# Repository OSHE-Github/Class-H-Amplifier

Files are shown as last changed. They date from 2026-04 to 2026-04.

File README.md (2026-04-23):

# Class-H-Amplifier

<p align="center">
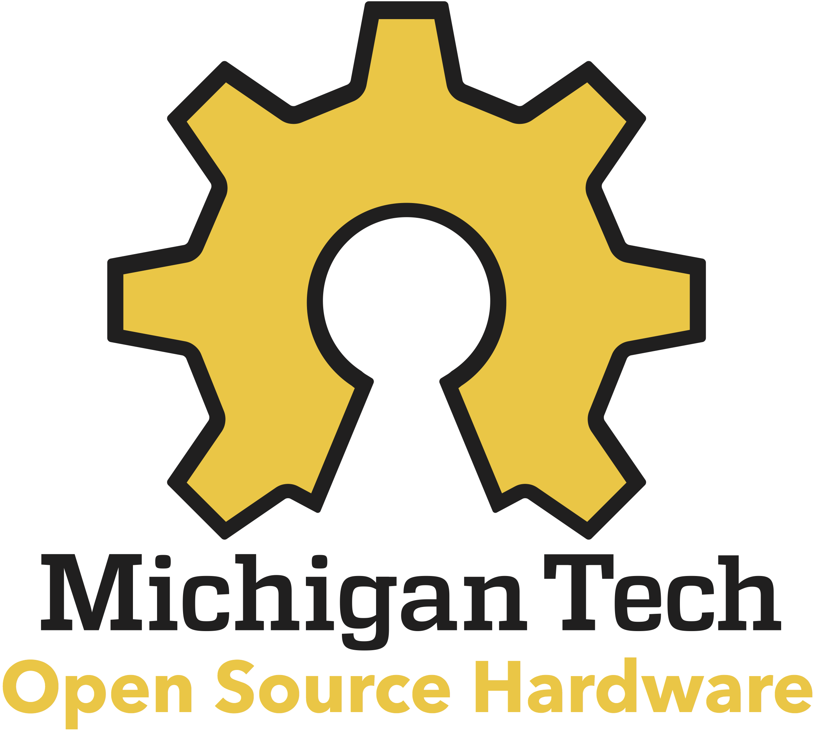
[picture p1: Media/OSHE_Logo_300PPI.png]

</p>

# Project Overview
This project aims to develop a lower-cost Class H amplifier design that can be used not only for audio, but other applications as well with little-to-no modification required. The design is based around a class AB amplifier like many reference designs. This amplifier design includes  documentation on testing and simulations to allow for easy replicability and modification. Key specifications and their impact on performance have been researched and were used to guide the design process. The design has been broken up into sections and most have been successfully simulated. These sections are shown in the block diagram.
<p align="center">

</p>

# Methodology
The class H amplifier was broken down into sections to design separately that would fit together in the end. A class H amplifier differs from other amplifier classes due to its modulating supply rails [1]. A class AB amplifier was frequently used in reference designs and is commonly used especially in audio applications, leading that class to be the choice for this design as well. 

Specifications were defined throughout the process, both to guide the design and to evaluate the actual performance of the completed design. Common amplifier specifications listed on commercial designs include those shown in Table 1, including more which do not apply, are difficult to set a target for,  or are not easily testable. Target values were defined based on typical values and on what was a reasonable goal for this project. The specifications and their values are listed in the table below. 

| Specification | Target |
|---|---|
| Maximum Output Power (Avg) | 100 W |
| Load Impedance | 8 Ω |
| Supply | ±6–45 V |
| Frequency Response | 20 Hz – 20 kHz |
| Total Harmonic Distortion (THD) | < 1% @ 1 kHz |
| Total Harmonic Distortion + Noise (THD+N) | < 1% @ 1 kHz |
| Signal to Noise Ratio (SNR) | ≥ 70 dB |
| Slew Rate | ≥ 5 V/µs |
| Efficiency | > 50% |
| Protection | Overvoltage, undervoltage, reverse polarity, undercurrent |

The full methodology is explained in more detail in the [project report](https://github.com/OSHE-Github/Class-H-Amplifier/blob/main/Documents/Class%20H%20Report.pdf).

# Bill of Materials
### Rail Follower
| Part Description | Part Number | Quantity | Unit Cost | Total Cost |
|---|---|---|---|---|
| 3.3 µH Sepic Inductor | ETQ-P8M3R3JFA | 2 | $2.34 | $4.68 |
| 1 µF Sepic Medium Frequency Cap | CL31B105KCHNFNE | 50 | $0.10 | $5.21 |
| MOSFET N-Channel 100V | SIR870DP-T1-GE3 | 1 | $3.23 | $3.23 |
| 120 V 20A Output Diode | FSV20120V | 1 | $1.30 | $1.30 |
| 10 mΩ 3W Shunt Resistor | CRA2512-FZ-R010ELF | 2 | $0.55 | $1.10 |
| 0.22 µF Soft Start Capacitor | C3216X7R2A224K115AA | 1 | $0.26 | $0.26 |
| 44.2 kΩ Rt Resistor | CRCW040244K2FKEDC | 3 | $0.10 | $0.30 |
| 10 kΩ Resistor | RC0402FR-0710KL | 4 | $0.10 | $0.40 |
| 22 kΩ Comp Resistor | ERA-2AEB223X | 1 | $0.10 | $0.10 |
| 4700 pF Comp Capacitor | GRM155R72A472KA01D | 1 | $0.10 | $0.10 |
| 330 µF Output Filter Capacitor | EKXJ161ELL331MK50S | 4 | $2.98 | $11.92 |
| Test Points | 36-5000-ND | 7 | $0.28 | $1.96 |
| XT-30 | FIT0586 | 2 | $1.90 | $3.80 |
| 7.5 kΩ Resistor | ERA-2AEB752X | 3 | $0.10 | $0.30 |
| 110 kΩ Resistor | 311-110KLRCT-ND | 1 | $0.10 | $0.10 |
| 10 µF ±10% 50V Input Capacitors | CL31A106KBHNNNE | 10 | $0.21 | $2.10 |
| TL072CDT Op-Amp | TL072CDT | 1 | $0.37 | $0.37 |
| 10 kΩ Potentiometer | PDB181-K220K-103B | 1 | $1.40 | $1.40 |
| Signal Rectifier | BAS4002ARPPE6327HTSA1 | 1 | $0.32 | $0.32 |
| 3.5mm Audio Jack | SJ1-3523N | 1 | $0.91 | $0.91 |

### Rail Splitter
| Part Description | Part Number | Quantity | Unit Cost | Total Cost |
|---|---|---|---|---|
| Half-Bridge Gate Driver IC | IRS21531DSTRPBFCT-ND | 2 | $1.24 | $2.48 |
| MOSFET N-CH 100V | SIR870DP-T1-GE3CT-ND | 4 | $3.23 | $12.92 |
| AD820ARZ Op-Amp | 505-AD820ARZ-ND | 2 | $9.11 | $18.22 |
| 10 µH Inductor | PCD2433CT-ND | 5 | $1.13 | $5.65 |
| Zener Diode | 1655-SK56BCT-ND | 5 | $0.49 | $2.45 |
| 5.6 kΩ 0.1% 1/10W | YAG1699CT-ND | 10 | $0.06 | $0.59 |
| 1 nF 1% 25V | 399-C0603C102F3GACTUCT-ND | 10 | $0.50 | $5.04 |
| 10 µF ±20% 100V | 490-GRM32EC72A106ME05KCT-ND | 15 | $0.64 | $9.56 |
| 10 µF ±10% 25V | 399-11939-1-ND | 10 | $0.13 | $1.26 |
| 470 µF 100 V | 493-1379-ND | 10 | $1.09 | $10.92 |
| 47 µF 100 V | 493-1147-ND | 10 | $0.28 | $2.80 |
| 10k Trimmer Pot | TC33X-103ECT-ND | 3 | $0.25 | $0.75 |
| 2200 pF ±20% 25V Ceramic | 399-C0603C222M3RACTUCT-ND | 10 | $0.15 | $1.47 |
| 0.1 µF ±10% 25V Ceramic | 399-C0603C104K3RACTUCT-ND | 10 | $0.01 | $0.10 |
| 33 kΩ ±0.1% 0.1W | P33KDBCT-ND | 10 | $0.06 | $0.61 |
| 330 Ω ±5% 0.1W | 311-330GRCT-ND | 10 | $0.02 | $0.20 |
| 3.9 kΩ ±1% 0.1W | RMCF0603FT3K90CT-ND | 10 | $0.01 | $0.06 |
| 12 kΩ ±0.1% 0.1W | P12KDBCT-ND | 10 | $0.06 | $0.61 |
| 3.3 kΩ ±1% 0.1W | RMCF0603FT3K30CT-ND | 10 | $0.01 | $0.06 |
| 82 kΩ ±5% 0.1W | 311-82KGRCT-ND | 10 | $0.01 | $0.07 |
| 4.7 kΩ ±1% 0.1W | RMCF0603FT4K70CT-ND | 10 | $0.01 | $0.06 |
| 10 Ω ±1% 0.1W | RMCF0603FT10R0CT-ND | 10 | $0.01 | $0.06 |
| 1.5 kΩ ±1% 0.25W | RHM1.50KADCT-ND | 10 | $0.08 | $0.75 |
| Test Point | 36-5005-ND | 30 | $0.26 | $7.68 |

### Class AB Amplifier
| Part Number | Part Description | Quantity | Unit Cost | Total Cost |
|---|---|---|---|---|
| 296-41370-2-ND | OPA454 Op-Amp | 1 | $7.18 | $7.18 |
| MJL21193GOS-ND | Output PNP BJT 250 V 16 A | 1 | $6.26 | $6.26 |
| MJL21194GOS-ND | Output NPN BJT 250 V 16 A | 1 | $6.26 | $6.26 |
| MJE15033GOS-ND | Driver PNP BJT 250 V 8 A | 2 | $2.10 | $4.20 |
| MJE15032GOS-ND | Driver NPN BJT 250 V 8 A | 2 | $2.10 | $4.20 |
| TTC004BQ-ND | NPN 160V 1.5A | 3 | $0.90 | $2.70 |
| TTA004BQ-ND | PNP 160V 1.5A | 2 | $0.81 | $1.62 |
| 541-WSLF3222L4000FE6CT-ND | Output Emitter Resistors 12W | 2 | $3.01 | $6.02 |
| 541-CRCW080540K0FKEACT-ND | 40 kΩ Resistor 1/4W | 2 | $0.12 | $0.24 |
| 541-4187-1-ND | 20 kΩ Resistor 1/4W | 1 | $0.10 | $0.10 |
| 541-1.00KCCT-ND | 1 kΩ Resistor 1/4W | 2 | $0.10 | $0.20 |
| 541-1.10KCCT-ND | 1.1 kΩ Resistor 1/4W | 1 | $0.10 | $0.10 |
| 311-3.60KFRCT-ND | 3.6 kΩ Resistor 1/4W | 1 | $0.10 | $0.10 |
| 541-100CCT-ND | 100 Ω Resistor 1/4W | 3 | $0.10 | $0.30 |
| 709-VPDD202W102K1GV001ECT-ND | 1 nF Filter Capacitor | 1 | $0.17 | $0.17 |
| 399-C1206C104K5RACTUCT-ND | 0.1 µF Bypass Capacitors | 2 | $0.08 | $0.16 |
| 478-12065A300JAT2ACT-ND | 30 pF Capacitor | 1 | $0.28 | $0.28 |
| 1712-CRGH1206F330RCT-ND | 330 Ω Resistor 1/2W | 1 | $0.10 | $0.10 |
| 118-PV36W102C01B00-ND | 1 kΩ Potentiometer | 1 | $1.53 | $1.53 |

## Enclosure
| Part Description | Qty | Link | Cost  |
|---|-----|---|---|
| #2 x 1/4" Pan Head Sheet Metal Screw | 12  | [Link](https://www.amazon.com/dp/B094XVJRQB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)  | $7.49 |
| 3mm x 20mm Hex Bolt | 4 | [Link](https://www.amazon.com/BNUOK-Socket-Screws-Threads-Spanner/dp/B0DJR2Q5LP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)  | $7.49 |
| M3-0.5mm Hex Nut | 4 | [Link](https://www.amazon.com/ZQZ-M3-0-5mm-Stainless-Hardware-Standard/dp/B0CQJK2R5T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)  | $9.99 |

# Tools Used
| Part Description | Part Number | Cost |
|---|---|---|
| Soldering Iron | FX888DX-010BY | $122.99 |
| Oscilliscope | DSOX2004A |  $3306.90 |
| B07BR3F9N6 | 3D Printer |  $169.00 |

Software:
- [LTspice](https://www.analog.com/en/resources/design-tools-and-calculators/ltspice-simulator.html)
- [KiCAD](https://www.kicad.org/download/)
  
# Assembly Overview
1. Gather materials specified in BOM
2. Order materials using provided Gerber files
3. Solder componenents on PCB as specified by schematics
4. Test as described in the [testing procedure](https://github.com/OSHE-Github/Class-H-Amplifier/blob/main/Documents/Testing%20Procedure.md)
5. Dowload enclosure files
6. 3D print enclosure
7. Secure PCBs in enclosure

Detailed assembly guide, including details on LTspice simulations can be found in the [project report](https://github.com/OSHE-Github/Class-H-Amplifier/blob/main/Documents/Class%20H%20Report.pdf)

# Future Recommendations
1. Further testing  for the final rendition of the rail follower board separately and the combination of the rail follower, rail splitter, and AB amplifier
2. Improve distortion, potentially through modification on rail splitter board
3. Further testing is needed for that to understand its maximum load conditions and how those can be improved
4. Additional testing with distortion using more precise equipment or measurement techniques

# References
[1] N. Utomo et al., “An 85.1% Peak Efficiency, Low Power Class H Audio Amplifier With Full Class H Operation,” *IEEE Transactions on Circuits and Systems I: Regular Papers*, vol. 70, no. 12, pp. 1–13, 2023. doi: 10.1109/TCSI.2023.3305622.

[2] S. Munz, “Slew Rate in Audio Amplifiers - What Does it Mean?,” *Audioholics*, Feb. 08, 2013.  
https://www.audioholics.com/audio-amplifier/amplifier-slew-rate

[3] Cambridge Audio, “Amplifier Specifications,” *Cambridge Audio*.  
https://www.cambridgeaudio.com/usa/en/blog/amplifier-specifications

[4] “What is Total Harmonic Distortion (THD)?,” *Audiophile On*, Aug. 16, 2025.  
https://www.audiophileon.com/news/what-is-total-harmonic-distortion-thd

[5] V. Batra, “Modular Concepts: What is an Envelope Follower?,” *Perfect Circuit*, Aug. 22, 2024.  
https://www.perfectcircuit.com/signal/envelope-followers

[6] “What’s the difference between MOSFET and BJT and how to choose?,” *NextPCB*.  
https://www.nextpcb.com/blog/what-is-the-difference-between-mosfet-and-bjt-and-how-to-choose

[7] A. Sedra and K. Smith, *Microelectronic Circuits*. Oxford University Press, 2019.

[8] O. Jørgensen, “What do different amplifier classes mean?,” *Dynaudio*, May 14, 2025.  
https://dynaudio.com/magazine/2025/may/amplifier-classes-ask-the-expert

[9] D. Self, *Audio Power Amplifier Design*, 6th ed. Elsevier / Focal Press, 2013.

[10] Cadence PCB Solutions, “What is Signal to Noise Ratio and How to calculate it?,” 2023.  
https://resources.pcb.cadence.com/blog/2020-what-is-signal-to-noise-ratio-and-how-to-calculate-it

[11] “OSHW,” *Freedom Defined*, 2023.  
https://freedomdefined.org/OSHW

This was also used as a general reference for various amplifier topics and designs that were not directly referenced in this report:

[12] B. Cordell, *Designing Audio Power Amplifiers*. McGraw-Hill Professional, 2010.

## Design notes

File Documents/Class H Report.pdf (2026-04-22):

# Class H Amplifier Report

Prepared by:

Owen Fabbricatore, Tori Frighetto, Peter Kocour, Ben May

### 1. Main Product Image

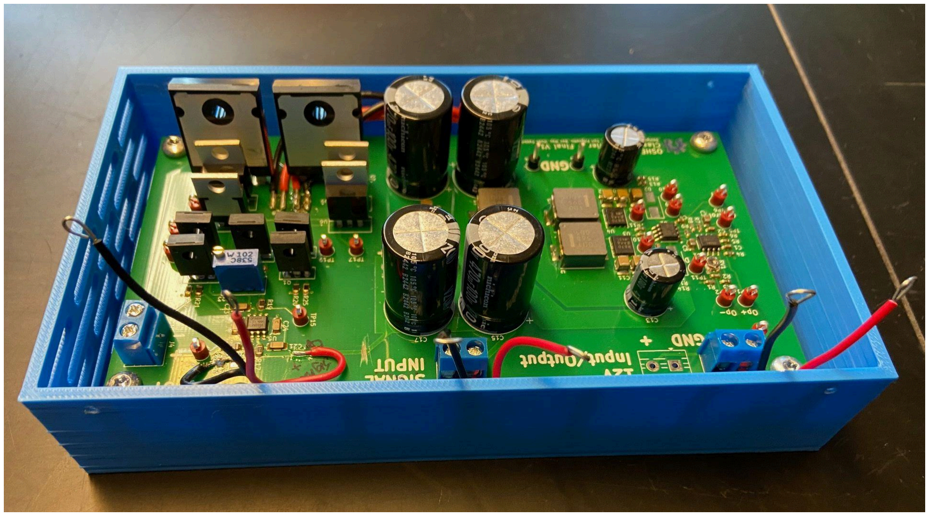
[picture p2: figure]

Figure 1. Product Image

### Table of Contents

### 2. Project Description

This project aims to develop a lower-cost Class H amplifier design that can be used not only for audio, but other applications as well with little-to-no modification required. The design is based around a class AB amplifier like many reference designs. Open source designs are uncommon and not well documented for this class of amplifier and commercial designs are expensive. This amplifier design will include clear documentation to allow for easy replicability and modification. Key specifications and their impact on performance have been researched and were used to guide the design process. The design has been broken up into sections and most have been successfully simulated. These sections are shown in the block diagram.

Figure 2. Block Diagram of Class H Amplifier

### 3. Methodology in Brief

The class H amplifier was broken down into sections to design separately that would fit together in the end. A class H amplifier differs from other amplifier classes due to its modulating supply rails [1]. A class AB amplifier was frequently used in reference designs and is commonly used especially in audio applications, leading that class to be the choice for this design as well.

### 3.1 Specifications

Specifications were defined throughout the process, both to guide the design and to evaluate the actual performance of the completed design. Common amplifier specifications listed on commercial designs include those shown in Table 1, including more which do not apply, are difficult to set a target for, or are not easily testable. Target values were defined based on typical values and on what was a reasonable goal for this project. The specifications and their values are listed in Table 1.

Table 1: Target Specifications

Specification | Target
Maximum Output Power (Avg) | 100 W

Load Impedance | 8Ω
Supply | ±6-45 V
Frequency Response | Minimum: 20 Hz - 20 kHz
Total Harmonic Distortion (THD) | <1% @ 1kHz
Total Harmonic Distortion + Noise (THD+N) | <1% @ 1kHz
Signal to Noise Ratio (SNR) | ≥70 dB
Slew Rate | ≥5 V/µs
Efficiency | >50%
Protection | Overvoltage, undervoltage, reverse polarity, undercurrent

The efficiency was selected based on the typical efficiency of an AB amplifier alone and efficiencies that higher-level class H designs achieved. With AB amplifiers typically having efficiency near 50%, the target is to at least improve on that efficiency. The slew rate was determined by the peak voltage that is expected, set by the defined output power and load, and the frequency which is 20 kHz for this calculation. The calculation for the peak voltage is given by

100 × 8 × | 2 = 40 V | (3.1)

The equation for slew rate is shown below [2].

Slew Rate = 2π × Frequency × Peak Voltage | (3.2)

Total harmonic distortion and total harmonic distortion + noise measures how closely the output of the amplifier matches the original signal and lower percentages are better [3]. In audio applications this affects the sound quality and in other applications this applies to inefficiency. Many high quality amplifiers have THD less than 0.05%, but typically below 1% is considered acceptable for audio products [4]. Acceptable THD varies based on application.

### 3.2 Protection & Enclosure

The Class-H amplifiers safety and protection are maintained through a combination of built in electrical safeguards on the PCB level and passive thermal management into the housing.

### 3.2.1 Integrated Board Protection

Protection is primarily handled via the built in circuitry on the envelope follower, which has overcurrent, undervoltage, overvoltage, and reverse polarity protection. Overcurrent protection is managed by an ATM mini (automotive mini fuse), while the LTC4367 from analog devices that provides the remaining voltage based safeguards. This IC is rated for -40V to 100V and utilizes a three resistor voltage divider to monitor the supply rails.The threshold limits are calculated as follows.

V

OV LIMIT = 0. 5 × 1 +

R

top+ R
mid
R
bot

( )
(3.3)

V

UV LIMIT = 0. 5 × 1 +

R
top
R

bot+R
mid

( )
(3.4)

Solving the above equations will give three resistors, and the SHDN pin from our example can be ignored.

### 3.2.2 General Design

The physical enclosure, designed in Autodesk Inventor, was designed as the final layer of protection by addressing thermal dissipation and electrical safety. Key design considerations include:
1. Thermal Management - To keep the boards cool, it was decided to use a 12V 50mm fan to blow air across the boards. The design features an intake on the top of the enclosure and carefully placed exhaust vents to direct airflow over the boards.
2. Component Layout - The interior is optimized to keep the overall size of the enclosure as small as possible, while still leaving ample space for repair and maintenance. The AB amp is mounted to the bottom plate of the enclosure and the envelope follower is mounted to the top, allowing air to flow over both boards and exhaust out of the front.
3. Exterior Shape - Initial designs were simple and boxy, but it was decided to add texture to the enclosure so the amplifier is more appealing aesthetically.
4. Mechanical Integrity - The enclosure was developed as three pieces, which prioritizes assembly and 3D printing. It was designed so no supports are needed when 3D printing and assembly requires no more than a dozen screws.

### 3.3 Envelope Follower

An envelope follower tracks an input signal’s amplitude and translates it into a voltage which can control other components in a system [5]. In a class H amplifier the envelope follower is necessary in order to control the AB amplifier’s supply voltage based on the input signal. This allows for improved power efficiency. The rail follower is based around the LM5155 in a SEPIC configuration. There are a few key advantages to using a SEPIC converter over other topologies. The first advantage of a SEPIC converter is that it is a buck/boost topology, this allows a wide output voltage range that can swing above or below the input voltage, this enables the rail follower to accept a wide voltage range from 10V-30V while still outputting the required 100 W. Another advantage is because a SEPIC converter input and output are capacitively coupled, no direct path exists from input to output like in a typical boost converter, this provides an extra layer of safety, ensuring no short circuit can occur across the rail follower. The audio envelope is generated by rectifying an AC audio source which is then fed into an op amp and 2uF capacitor and connected to the feedback pin of the LM5155. This setup creates an envelope with a fast rising edge and slow falling edge. Figure 3 shows the schematic for this circuit. The specifications for the circuit are described in Table 2.

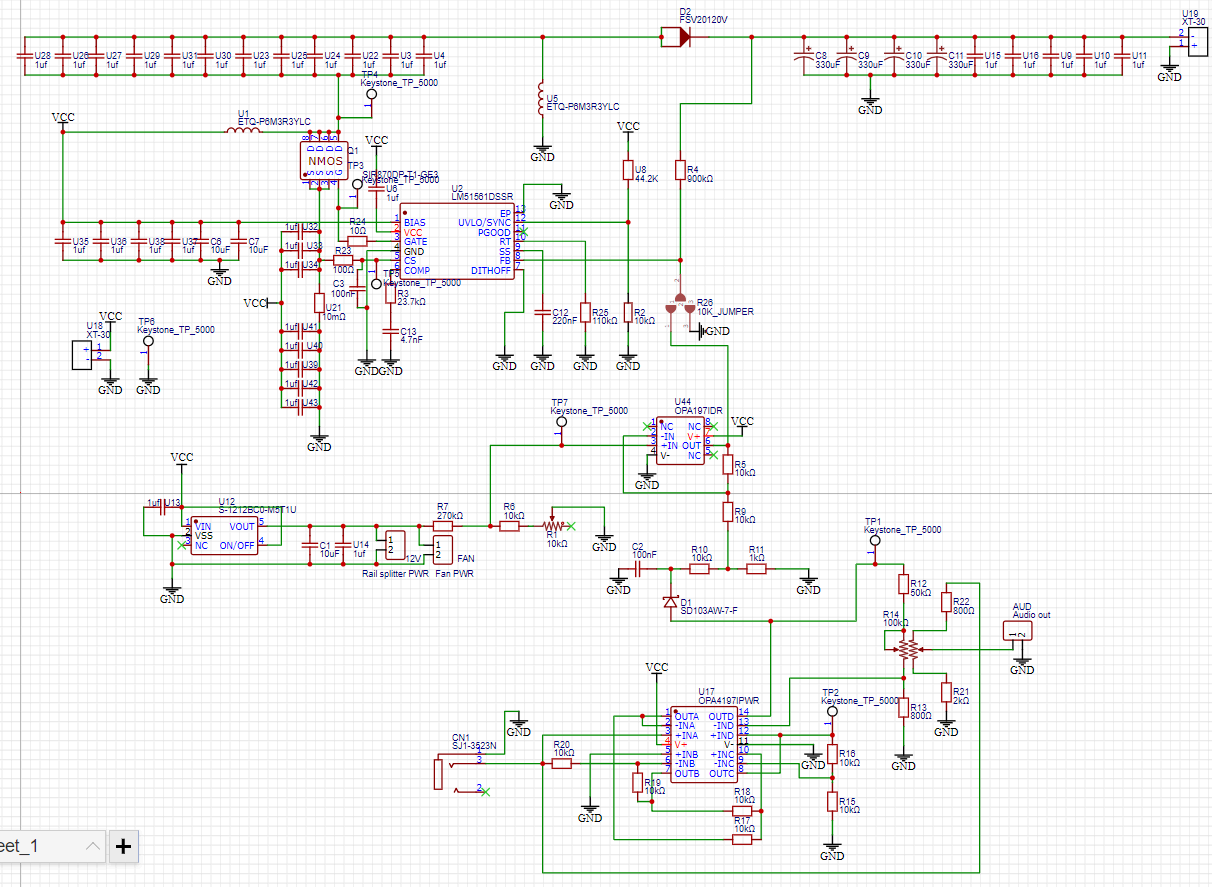
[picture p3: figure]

Figure 3: Envelope Follower Schematic

Table 6:Envelope Follower Circuit Specifications

Input Voltage Range | 10 V-30 V
Output Power | Up to 300 W
Output Voltage Range | 12 V-90 V

Switching Frequency | 250 kHz

### 3.4 Rail Splitter

### 3.4.1 General Design

The rail splitter topology was based off of a design that was made by MrSlehofer on OSHWLAB and is licensed with a CERN Open Hardware License. The initial design utilizes the IR21531D bridge driver, though this device was at the end of life prior to this project. That component was replaced with the IR21531PBF as the half bridge driver for our design. In addition to this, the original operational amplifier used in the feedback loop was replaced with an AD820, this op amp has a higher slew rate which was intended to help increase the response of the feedback loop and ultimately reduce the amount of ripple in the output voltage rails. In addition, the power management portion of the design was removed as our class H amplifier will already have the needed power rails to power the op amp and IC within this portion. The rest of the design stayed relatively the same with the only change being the wattage values of some components to accommodate the higher voltage levels of our desired output.

### 3.4.2 Function Overview

The rail splitter works by having a half bridge driver send alternating PWM signals to two SIR870DP-T1-GE3 MOSFETs. One is between the top and middle rail, while the other is between the middle and bottom rail. As the driver output signals the MOSFET alternates between cutoff and triode, allowing for the rails to evenly split between the voltages. Following this stage there is a filter stage which would level the ripple that is created by the oscillations induced by the opening and closing of the MOSFETs. Finally there is a feedback loop that allows the rails to adapt to different loads that are applied. This feedback loop utilizes an op amp that will switch between its rails based on if the output is past a set threshold. This output is then connected to the RC network that controls the frequency of the output of the half bridge driver.
The default PWM frequency that was selected is based on Equation 3.5 and is based on the values that are selected for RT and CT. For our design we choose RT to be 5.6 kΩ and CT to be 1nF using these values and frequency equation it can be determined that the default frequency is around 125 kHz. When the feedback loop is low it drives the network signal high which opens the gate between high and middle. Contrasting this when the feedback loop is high it drives the network low which then closes that gate and opens the gate to ground. This means that when the output is around the desired voltage the feedback will open and close the gates as needed to maintain that value.

f =

1
1.453 * RT * CT

(3.5)

The output rail of this segment is the original voltage on the top rail, followed by half of that voltage on the middle rail and then ground on the bottom rail. To get a negative and positive rail the middle rail is utilized at the ground reference moving forward. This allows the bottom rail to be a negative rail and the top rail to be the positive rail. To get the desired range of ±6 - 45V the rail splitter is able to handle an input voltage of 12 - 90V.

### 3.5 AB Amplifier

The AB amplifier was initially designed and simulated for the high end, ±45 V, of the decided voltage range in order to select components that were rated for the higher voltage. Modifications to the design are still needed to get the AB amplifier to operate correctly at the lower end of the voltage range.

### 3.5.1 Transistors

Before beginning the design, the use of BJTs or MOSFETs was evaluated to determine which would be most suitable for this design. BJTs offer better linearity than MOSFETs, which is a key factor in this amplifier especially for audio applications. The use of BJTs allows the amplifier to produce a more accurate translation of the output signal. MOSFETs also require careful biasing for gate voltage control which increases the complexity of the design. This is not desirable for the open-source and easily replicable goal of this project. While MOSFETs have better thermal stability and lower power consumption than BJTs, these factors can be managed more easily through thermal considerations in board design [6].

### 3.5.2 General Design

Various general designs were considered for the AB amplifier such as a fully discrete design with BJTs or MOSFETs, a fully differential design with BJTs or MOSFETs, an op-amp input stage with a discrete output stage, or an IC to handle the input and VAS stage with a discrete output stage. The fully discrete designs would provide great flexibility and performance but would come with more components and complexity. A fully differential design would have high efficiency and lower distortion but high complexity because of common-mode feedback and matched stages, making it harder for others to recreate or modify with understanding. Using an IC for the majority of the amplifier would simplify the design significantly making it easier to reproduce as well as decrease the size, but there is less flexibility and limitations in IC availability. An op-amp was chosen for the input stage because it simplifies the design by setting gain and feedback. It can potentially limit performance and there is less control over gain structure, but there is a wide selection of op-amps available with high slew rates and low noise that are also compatible with high voltage rails.

### 3.5.3 Output Stage and Biasing

The class AB output stage, a combination of class A and class B output stages, has two complementary output transistors like a class B output stage but they are biased at small current to reduce crossover distortion. The crossover distortion that would appear in the similar class B stage is reduced because there is a smooth transition between transistor conduction as voltage changes [7]. A class AB output stage is not the most efficient, typically around 50%, but it balances the advantages and disadvantages of the class A and class B designs, specifically linearity and efficiency [8]. Class AB amplifiers are also very common, especially in audio, which gives the advantage of more reference designs to evaluate and learn from. The lower efficiency of the AB output stage over another output stage, like a class D, is not critical because the circuitry added to make it a class H amplifier improves this efficiency.
Biasing methods were considered to supply the base currents for the output stage. Two common methods were evaluated that would both provide thermal stability which was an important consideration due to the power dissipation from the output stage that could damage the output transistors [7]. Diodes are a simple method that would protect the output transistors from damage. A VBE multiplier was used instead of diodes because it provides greater flexibility in the voltage value that sets the quiescent current. Figure 4 shows the VBE multiplier configuration for biasing an AB output stage.

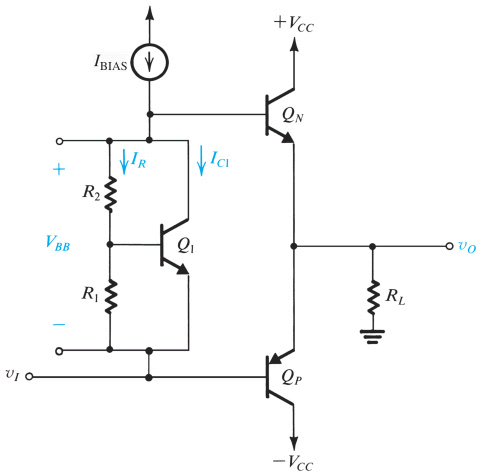
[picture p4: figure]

Figure 4: VBE Multiplier [7]

### 4. Bill of Materials (BOM)

Table 3: Rail Follower

Part Description | Part Number | Quantity | Unit Cost | Total Cost
3.3 µH Sepic Inductor | ETQ-P8M3R3JFA (https://www.digikey.com/en/products/detail/panasonic-electronic-components/ETQ-P8M3R3JFA/7802524) | 2 | $2.34 | $4.68
1 µF Sepic Medium Frequency cap | CL31B105KCHNFNE (https://www.digikey.com/en/products/detail/samsung-electro-mechanics/CL31B105KCHNFNE/3888752) | 50 | $0.10 | $5.21
Mosfet N-Channel 100V | SIR870DP-T1-GE3 (https://www.digikey.com/en/products/detail/vishay-siliconix/SIR870DP-T1-GE3/3748949) | 1 | $3.23 | $3.23
120 V 20A Output Diode | FSV20120V (https://www.digikey.com/en/products/detail/onsemi/FSV20120V/5306666) | 1 | $1.30 | $1.30
10 mOhms 3W Shunt Resistor | CRA2512-FZ-R010ELF (https://www.digikey.com/en/products/detail/bourns-inc/CRA2512-FZ-R010ELF/1775029) | 2 | $0.55 | $1.10

0.22 µF Soft Start Capacitor | C3216X7R2A224K115AA (https://www.digikey.com/en/products/detail/tdk-corporation/C3216X7R2A224K115AA/789677) | 1 | $0.26 | $0.26
44.2 kOhms Rt resistor | CRCW040244K2FKEDC (https://www.digikey.com/en/products/detail/vishay-dale/CRCW040244K2FKEDC/7928528) | 3 | $0.10 | $0.30
10 kOhm Resistor | RC0402FR-0710KL (https://www.digikey.com/en/products/detail/yageo/RC0402FR-0710KL/726523) | 4 | $0.10 | $0.40
22 kOhms Comp Resistor | ERA-2AEB223X (https://www.digikey.com/en/products/detail/panasonic-electronic-components/ERA-2AEB223X/1706037) | 1 | $0.10 | $0.10
4700 pF Comp Capacitor | GRM155R72A472KA01D (https://www.digikey.com/en/products/detail/murata-electronics/GRM155R72A472KA01D/965899) | 1 | $0.10 | $0.10
330 µF Output Filter Capacitor | EKXJ161ELL331MK50S (https://www.digikey.com/en/products/detail/nichicon/UCY2C331MHD6TN/3129796) | 4 | $2.98 | $11.92
Test Points | 36-5000-ND (https://www.digikey.com/en/products/detail/keystone-electronics/5000/255326?gclsrc=aw.ds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) | 7 | $0.28 | $1.96
XT-30 | FIT0586 (https://www.digikey.com/en/products/detail/dfrobot/FIT0586/9559255?gclsrc=aw.ds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) | 2 | $1.90 | $3.80
7.5 kOhm Resistor | ERA-2AEB752X (https://www.digikey.com/en/products/detail/panasonic-electronic-components/ERA-2AEB752X/1706026) | 3 | $0.10 | $0.30
110 kOhm Resistor | 311-110KLRCT-ND (https://www.digikey.com/en/products/detail/yageo/RC0402FR-07110KL/726531) | 1 | $0.10 | $0.10
10 µF ±10% 50V Input Capacitors | CL31A106KBHNNNE (https://www.digikey.com/en/products/detail/samsung-electro-mechanics/CL31A106KBHNNNE/3888534) | 10 | $0.21 | $2.10
TL072CDT Op-Amp | TL072CDT (https://www.digikey.com/en/products/detail/stmicroelectronics/TL072CDT/599372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) | 1 | $0.37 | $0.37
10 kOhm Potentiometer | PDB181-K220K-103B (https://www.digikey.com/en/products/detail/bourns-inc/PDB181-K220K-103B/3780701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) | 1 | $1.40 | $1.40
Signal Rectifier | BAS4002ARPPE6327HTSA1 (https://www.digikey.com/en/products/detail/infineon-technologies/BAS4002ARPPE6327HTSA1/2023140) | 1 | $0.32 | $0.32
3.5mm Audio Jack | SJ1-3523N (https://www.digikey.com/en/products/detail/same-sky-formerly-cui-devices/SJ1-3523N/738689) | 1 | $0.91 | $0.91

Table 4: Rail Splitter

Part Description | Part Number | Quantity | Unit Cost | Total Cost
Half-Bridge Gate Driver IC | IRS21531DSTRPBFCT-ND (https://www.digikey.com/en/products/detail/infineon-technologies/irs21531dstrpbf/1300645) | 2 | $1.24 | $2.48
MOSFET N-CH 100V | SIR870DP-T1-GE3CT-ND (https://www.digikey.com/en/products/detail/vishay-siliconix/SIR870DP-T1-GE3/3748949) | 4 | $3.23 | $12.92
AD820ARZ Op-Amp | 505-AD820ARZ-ND (https://www.digikey.com/en/products/detail/analog-devices-inc/AD820ARZ/620917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) | 2 | $9.11 | $18.22
10uH Inductor | PCD2433CT-ND (https://www.digikey.com/en/products/detail/panasonic-electronic-components/ETQ-P5M100YFC/5357809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) | 5 | $1.13 | $5.65
Zener Diode | 1655-SK56BCT-ND (https://www.digikey.com/en/products/detail/smc-diode-solutions/SK56B/6022696) | 5 | $0.49 | $2.45
5.6K 0.1% 1/10W | YAG1699CT-ND (https://www.digikey.com/en/products/detail/yageo/RT0603BRD075K6L/1072597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) | 10 | $0.06 | $0.59
1nF 1% 25V | 399-C0603C102F3GACTUC | 10 | $0.50 | $5.04
T-ND (https://www.digikey.com/en/products/detail/kemet/C0603C102F3GACTU/2199692)
10 µF ±20% 100V | 490-GRM32EC72A106ME0 5KCT-ND (https://www.digikey.com/en/products/detail/murata-electronics/GRM32EC72A106ME05K/17860690) | 15 | $0.64 | $9.56
10 µF ±10% 25V | 399-11939-1-ND (https://www.digikey.com/en/products/detail/kemet/C0805C106K3PACTU/5267604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) | 10 | $0.13 | $1.26
470 µF 100 V | 493-1379-ND (https://www.digikey.com/en/products/detail/nichicon/UVZ2A471MHD/589120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) | 10 | $1.09 | $10.92
47 µF 100 V | 493-1147-ND (https://www.digikey.com/en/products/detail/nichicon/UVR2A470MPD/588888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) | 10 | $0.28 | $2.80
10k Trimmer Pot | TC33X-103ECT-ND (https://www.digikey.com/en/products/detail/bourns-inc/TC33X-2-103E/612858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) | 3 | $0.25 | $0.75
2200 pF ±20% 25V Ceramic | 399-C0603C222M3RACTU (https://www.digikey.com/en/products/detail/kemet/C0603C222M3RACTU/2200267) | 10 | $0.15 | $1.47

| CT-ND (https://www.digikey.com/en/products/detail/kemet/C0603C222M3RACTU/2200267)
0.1 µF ±10% 25V Ceramic | 399-C0603C104K3RACTUC T-ND (https://www.digikey.com/en/products/detail/kemet/C0603C104K3RACTU/416044) | 10 | $0.01 | $0.10
33 kOhms ±0.1% 0.1W | P33KDBCT-ND (https://www.digikey.com/en/products/detail/panasonic-electronic-components/ERA-3AEB333V/1465890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) | 10 | $0.06 | $0.61
330 Ohms ±5% 0.1W | 311-330GRCT-ND (https://www.digikey.com/en/products/detail/yageo/RC0603JR-07330RL/726769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) | 10 | $0.02 | $0.20
3.9 kOhms ±1% 0.1W | RMCF0603FT3K90CT-ND (https://www.digikey.com/en/products/detail/stackpole-electronics-inc/RMCF0603FT3K90/1713908) | 10 | $0.01 | $0.06
12 kOhms ±0.1% 0.1W | P12KDBCT-ND (http://www.digikey.com/en/products/detail/panasonic-electronic-components/ERA-3AEB123V/1465880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) | 10 | $0.06 | $0.61
3.3 kOhms ±1% 0.1W | RMCF0603FT3K30CT-ND (https://www.digikey.com/en/products/detail/stackpole-electronics-inc/RMCF0603FT3K30/1761032) | 10 | $0.01 | $0.06
82 kOhms ±5% 0.1W | 311-82KGRCT-ND (https://www.digikey.com/en/products/detail/yageo/RC0603JR-0782KL/726835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) | 10 | $0.01 | $0.07
4.7 kOhms ±1% 0.1W | RMCF0603FT4K70CT-ND (https://www.digikey.com/en/products/detail/stackpole-electronics-inc/RMCF0603FT4K70/1760998) | 10 | $0.01 | $0.06
10 Ohms ±1% 0.1W | RMCF0603FT10R0CT-ND (https://www.digikey.com/en/products/detail/stackpole-electronics-inc/RMCF0603FT10R0/1761152) | 10 | $0.01 | $0.06
1.5 kOhms ±1% 0.25W | RHM1.50KADCT-ND (https://www.digikey.com/en/products/detail/rohm-semiconductor/ESR03EZPF1501/1983433) | 10 | $0.08 | $0.75
Test Point | 36-5005-ND (https://www.digikey.com/en/products/detail/keystone-electronics/5005/255329) | 30 | $0.26 | $7.68

Table 5: AB Amplifier

Part Number | Part Description | Quantity | Unit Cost | Total Cost
OPA454 Op-amp | 296-41370-2-ND (https://www.digikey.com/en/products/detail/texas-instruments/OPA454AIDDAR/1899758) | 1 | $7.18 | $7.18
Output PNP BJT 250 V 16 A | MJL21193GOS-ND (https://www.digikey.com/en/products/detail/onsemi/MJL21193G/919549) | 1 | $6.26 | $6.26
Output NPN BJT 250 V 16 A | MJL21194GOS-ND (https://www.digikey.com/en/products/detail/onsemi/MJL21194G/919550) | 1 | $6.26 | $6.26
Driver PNP BJT 250 V 8 A | MJE15033GOS-ND (https://www.digikey.com/en/products/detail/onsemi/mje15033g/919494) | 2 | $2.10 | $4.20
Driver NPN BJT 250 V 8 A | MJE15032GOS-ND (https://www.digikey.com/en/products/detail/onsemi/MJE15032G/919493?s=N4IgTCBcDaILYCsCmBGArABgMxgOYgF0BfIA) | 2 | $2.10 | $4.20
NPN 160V 1.5A | TTC004BQ-ND (https://www.digikey.com/en/products/detail/toshiba-semiconductor-and-storage/TTC004B-Q/6600430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) | 3 | $0.90 | $2.70
PNP 160V 1.5A | TTA004BQ-ND (https://www.digikey.com/en/products/detail/toshiba-semiconductor-and-storage/TTA004B-Q/6600426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) | 2 | $0.81 | $1.62
Output Emitter Resistors 12W | 541-WSLF3222L4000FE6CT-N D (https://www.digikey.com/en/products/detail/vishay-dale/WSLF3222L4000FE6/25701010) | 2 | $3.01 | $6.02
40 kOhm Resistor 1/4W | 541-CRCW080540K0FKEACT-N D (https://www.digikey.com/en/products/detail/vishay-dale/CRCW080540K0FKEA/5075239) | 2 | $0.12 | $0.24
20 kOhm Resistor 1/4W | 541-4187-1-ND (https://www.digikey.com/en/products/detail/vishay-dale/CRCW120620K0FKEAC/7928609) | 1 | $0.10 | $0.10
1 kOhm Resistor 1/4W | 541-1.00KCCT-ND (https://www.digikey.com/en/products/detail/vishay-dale/CRCW08051K00FKEA/1175637) | 2 | $0.10 | $0.20
1.1 kOhm Resistor 1/4W | 541-1.10KCCT-ND (https://www.digikey.com/en/products/detail/vishay-dale/CRCW08051K10FKEA/1175641) | 1 | $0.10 | $0.10
3.6 kOhm Resistor 1/4W | 311-3.60KFRCT-ND (https://www.digikey.com/en/products/detail/yageo/RC1206FR-073K6L/728781) | 1 | $0.10 | $0.10
100 Ohm resistor 1/4W | 541-100CCT-ND (https://www.digikey.com/en/products/detail/vishay-dale/CRCW0805100RFKEA/1175523) | 3 | $0.10 | $0.30
1 nF Filter Capacitor | 709-VPDD202W102K1GV001E CT-ND (https://www.digikey.com/en/products/detail/johanson-dielectrics-inc/VPDD202W102K1GV001E/1556359) | 1 | $0.17 | $0.17

0.1 µF Bypass Capacitors | 399-C1206C104K5RACTUCT-N D (https://www.digikey.com/en/products/detail/kemet/C1206C104K5RACTU/411248) | 2 | $0.08 | $0.16
30 pF Capacitor | 478-12065A300JAT2ACT-ND (https://www.digikey.com/en/products/detail/kyocera-avx/12065A300JAT2A/1604535) | 1 | $0.28 | $0.28
330 Ohm Resistor 1/2W | 1712-CRGH1206F330RCT-ND (https://www.digikey.com/en/products/detail/te-connectivity-passive-product/CRGH1206F330R/7495002) | 1 | $0.10 | $0.10
1 kOhm Potentiometer | 118-PV36W102C01B00-ND (https://www.digikey.ca/en/products/detail/bourns-inc/PV36W102C01B00/666501) | 1 | $1.53 | $1.53

Table 6: Enclosure

Part | Qty | Link | Cost
#2 x 1/4" Pan Head Sheet Metal Screw | 12 | Link (https://www.amazon.com/dp/B094XVJRQB?oas=true) | $7.49

3mm x 20mm Hex Bolt | 4 | Link (https://www.amazon.com/BNUOK-Socket-Screws-Threads-Spanner/dp/B0DJR2Q5LP?s=industrial) | $7.49
M3-0.5mm Hex Nut | 4 | Link (https://www.amazon.com/ZQZ-M3-0-5mm-Stainless-Hardware-Standard/dp/B0CQJK2R5T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) | $9.99

### 5. Tools Used

Table 7: Tools Used

Part Number | Part Description | Quantity | Unit Cost | Total Cost
FX888DX-010BY (https://www.jensentools.com/product/10305267-FX888DX-010BY) | Soldering Iron | 1 | $122.99 | $122.99
DOS1102 (https://www.amazon.com/HANMATEK-Bandwidth-Oscilloscope-Channels-Professional/dp/B0833YFNKP) | Oscilloscope | 1 | $135.99 | $135.99
B07BR3F9N6 (https://www.amazon.com/Comgrow-Creality-Ender-Aluminum-220x220x250mm/dp/B07BR3F9N6) | 3D Printer | 1 | $169.00 | $169.00

Software Used:
- LTspice:
https://www.analog.com/en/resources/design-tools-and-calculators/ltspice-simulator.html
- KiCAD: https://www.kicad.org/download/

### 6. Assembly Instructions

### 6.1 Downloading and Setting Up LTspice

1. Go to
https://www.analog.com/en/resources/design-tools-and-calculators/ltspice-simulator.html
2. Choose the correct download for your operating system (Windows or Mac)
3. Download the schematic, symbol, and model files from github at https://github.com/OSHE-Github/Class-H-Amplifier

4. Put the downloaded files in your LTspice folder in Documents/LTspice
5. To open the schematic files, double click on them in the folder or open within LTspice by choosing File -> Open and then select an LTspice Schematic File

### 6.2 Protection Simulation Setup

1. Open the LTC4367_12_20.asc file in LTspice
2. Use the following for the voltage source
a. PWL(0 0 10m 15 50m 15 51m 22 100m 22 101m 15 150m 15 151m 10 200m 10 201m 15 250m 15 251m -15 300m -15)
3. Right click on the .dc directive to run a voltage sweep simulation
4. Run the simulation
5. Click on Vout and Vin to view the waveforms on the plot

### 6.3 Rail Splitter Simulation Setup

1. Open the Rail_Splitter_Sim.asc file in LTspice
2. Right click on the voltage source V2 circled in red in Figure 5

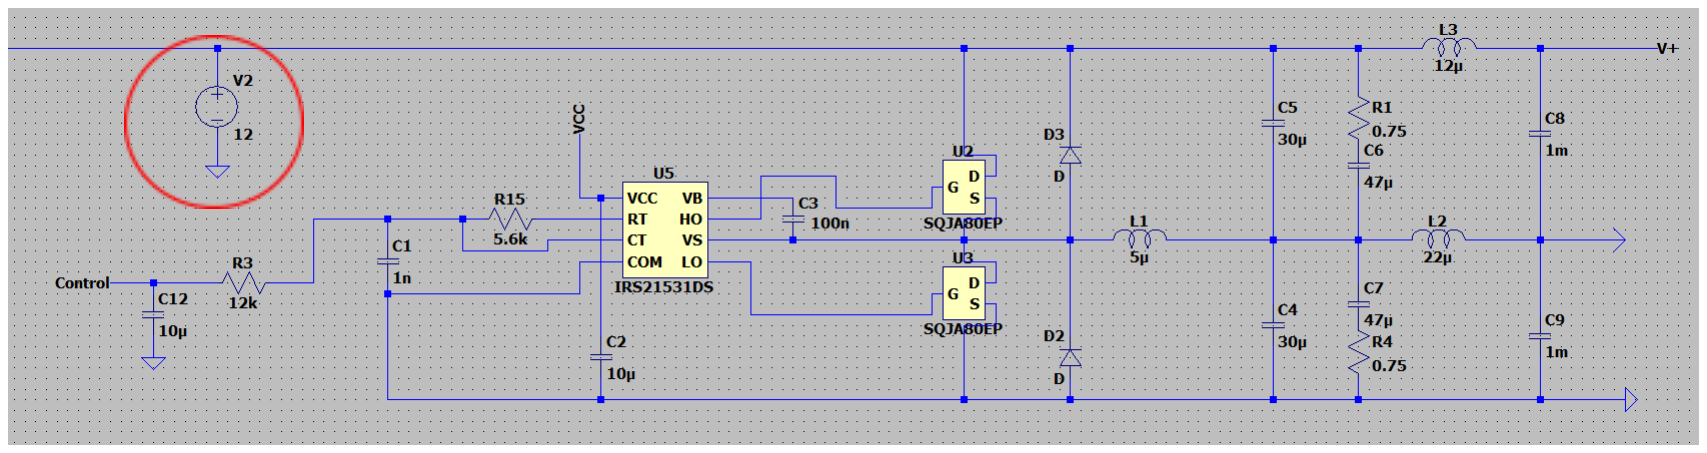
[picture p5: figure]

Figure 5: Rail Splitter
3. In the voltage source settings window set the voltage to twice the values you want your rails to be

Figure 6: Voltage Source Settings
4. Select the run button in the top right corner, or press alt+r on the keyboard
5. Probe the value of V+ and COM (the middle rail)
a. Confirm that the rails properly split your desired voltage
6. Probe around the circuit to measure any other desired values

### 6.4 AB Amplifier Simulation Setup

6.4.1 1 kHz Transient Simulation

1. Open the ABAmp_models85.asc file in LTspice
2. Right click on the voltage source V3 and choose SINE under functions.
3. Below the functions, enter the following parameters
a. Amplitude[V]: 1
b. Freq[Hz]: 1k
c. Ncycles: 16 - this can be changed
d. The other parameters can be left at 0

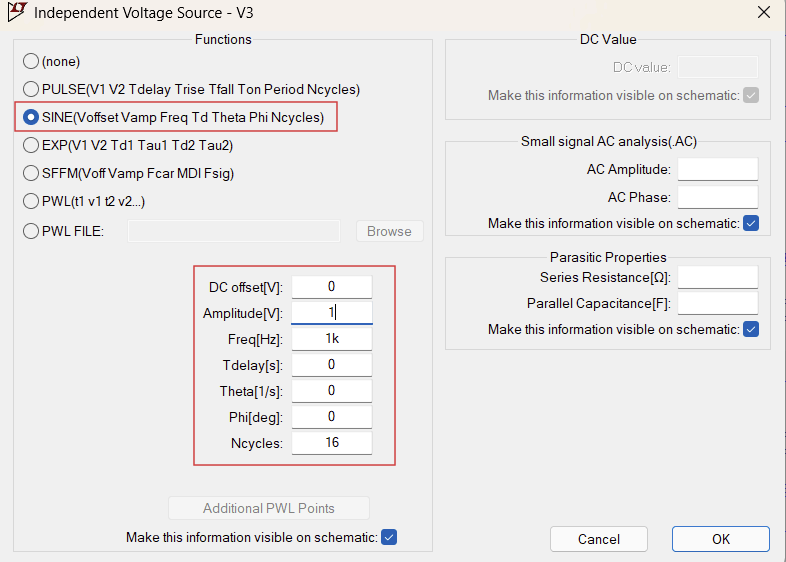
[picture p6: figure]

Figure 7: Voltage Source Configuration Window
4. Right click on the text “.tran 0 16ms 0 0.488u”
a. This is the syntax to run the transient simulation. The amount of time (16ms) for the simulation to run can be changed, but should run for at least a few milliseconds for it to stabilize.
b. The maximum timestep (0.488u) can also be changed and may give slightly different results but will mostly be the same. Too high of a max timestep may prevent the simulation from converging.

Figure 8: Transient Simulation Directive
5. Click OK
6. Press the Run button on the toolbar
7. The details of the simulation running will be shown at the bottom of the screen
8. A window will pop up that may show waveforms already selected or it may be blank
a. If blank, click on the Vout signal on the schematic and the waveform will appear in the other window. Alt + click on the resistor RL will bring up the waveform showing the output power
9. CTRL + click on the trace names will bring up a small window showing the RMS value of the signal and the average value
a. Here the RMS output voltage and the average power can be seen
10. The input voltage V3 can be adjusted by increasing the amplitude
a. 1.5 V amplitude gives the maximum average output power. Increasing beyond that the simulation will fail to converge. This issue is being worked on

### 6.4.2 Total Harmonic Distortion Simulation

1. This simulation uses the same input voltage settings and the same .tran analysis. The directive .four 1kHz 10 4 V(vout) is already included to view the FFT and THD
2. With a 1V amplitude, rerun the transient simulation

3. Right click anywhere on the plot and choose View -> FFT

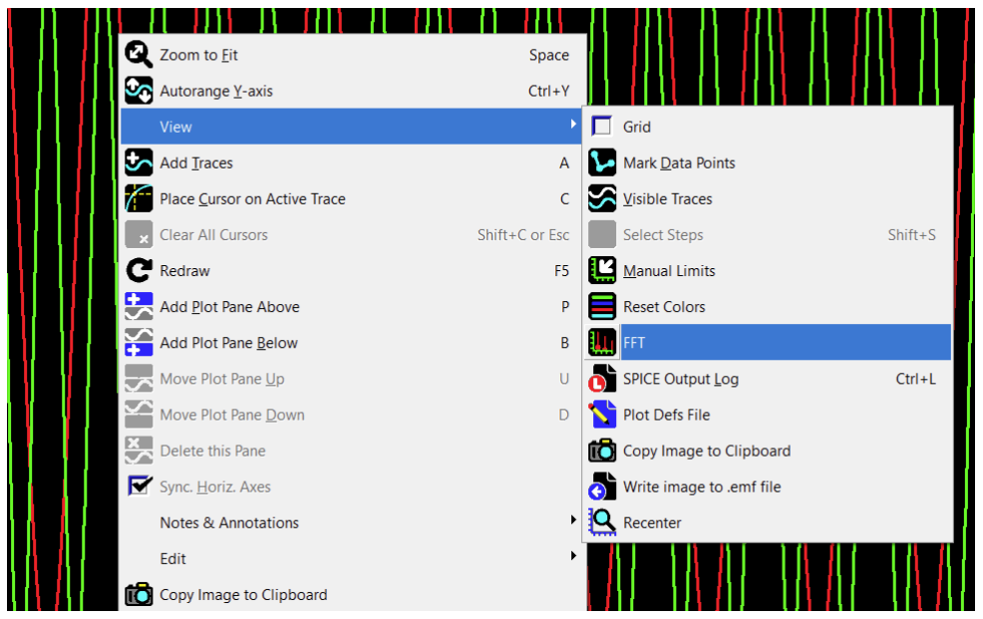
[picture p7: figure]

Figure 9: View FFT Option

4. A window will pop up with settings, shown below

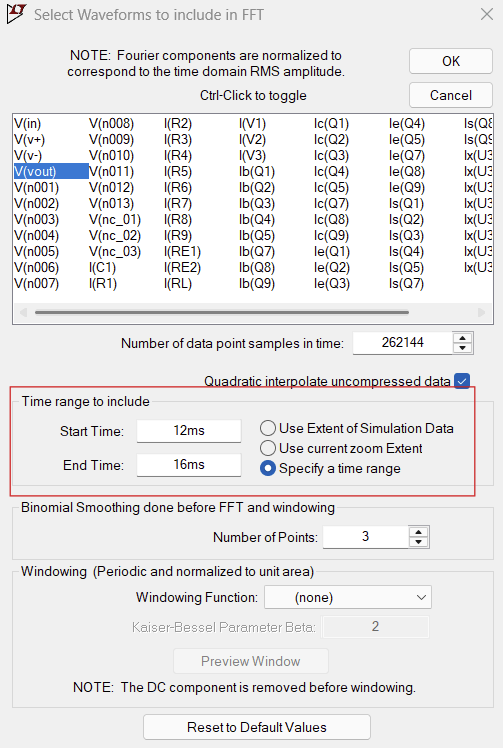
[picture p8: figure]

Figure 10: FFT Settings
5. Under time range select “Specify a time range” and use the simulation time for the end time and use the end time - 4ms for the start time

6. Click OK and the FFT plot will appear. The resolution will change depending on the timestep used in the simulation
7. Hit CTRL + L and the Spice Output Log will pop up
8. Scroll to the bottom to see the Fourier components details and the partial and total harmonic distortion

### 6.4.3 Noise Simulation

1. In the schematic window right click on the directive .noise V(vout) V3 dec 20 20 20k
2. A window with options to configure the analysis will appear. The current configuration is shown below

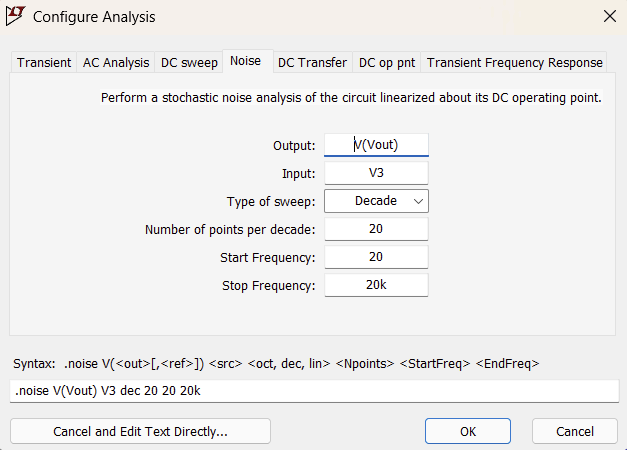
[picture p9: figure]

Figure 11: Noise Simulation Configuration

3. Change the settings if necessary and hit OK
4. Run the simulation
5. A blank plot will open, click on Vout on the schematic to plot that signal
6. CTRL + left click on the trace name v(onoise) will bring up a window with the total RMS noise

Figure 12: Noise Details Window

### 6.4.4 Frequency Response Simulation

1. Change the input voltage V3 to an AC 1 source by using the configuration shown below

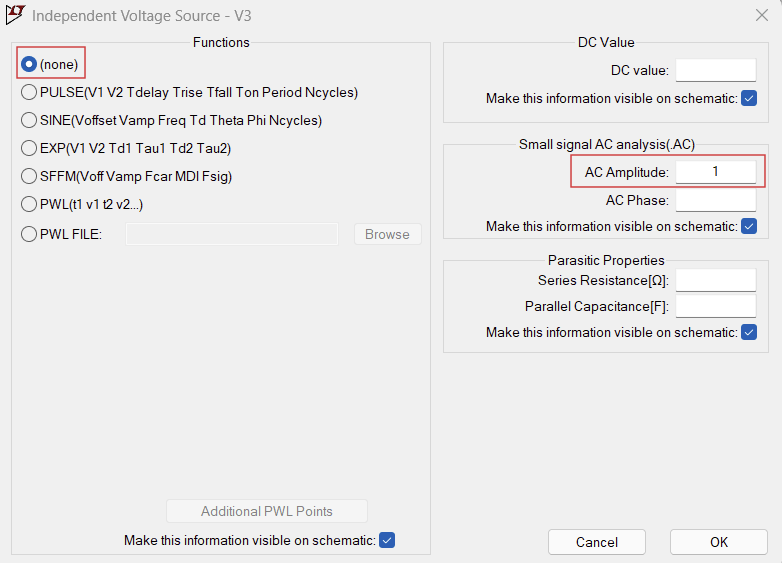
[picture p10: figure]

Figure 13: Voltage Configuration for Frequency Response Simulation
2. Right click on the directive .ac dec 10 20 1Meg
3. A window to configure the analysis will appear
a. The current configuration is a decade sweep with 10 points per decade from 20 Hz to 1 MHz
4. Hit OK and run the simulation
5. A blank plot window will appear
6. Click on Vout on the schematic window and the plot will appear with the frequency response
7. Left click on the trace name and a cursor will appear. Leave this cursor on the flat slope
8. Left click again on the trace and a second cursor will appear
9. Drag this cursor to the right until there is a difference of about 3dB between the two cursor magnitudes

Figure 14: Frequency Response Plot Cursor Details
10. The frequency response will be the frequency at cursor 1 to the frequency at cursor 2

### 6.5 Hardware Setup

### 6.5.1 Rail Follower Assembly

Following the schematic for the Rail follower and the bill of materials in section 4, place each component in its corresponding location on the PCB. The KiCAD file for the PCB can be found here: https://github.com/OSHE-Github/Class-H-Amplifier/tree/main/ClassH_PCB/envelope_follower

### 6.5.2 Rail Splitter and AB Amplifier Assembly

Following the schematics for the rail splitter in Figure 15 and the AB amplifier in Figure 16, along with the Bill of Materials and the reference designators, place each component onto the corresponding location on the PCB in Figure 17. All KiCAD files can be found on our GitHub under “ClassH_PCB_FINAL” at https://github.com/OSHE-Github/Class-H-Amplifier/tree/main/ClassH_PCB

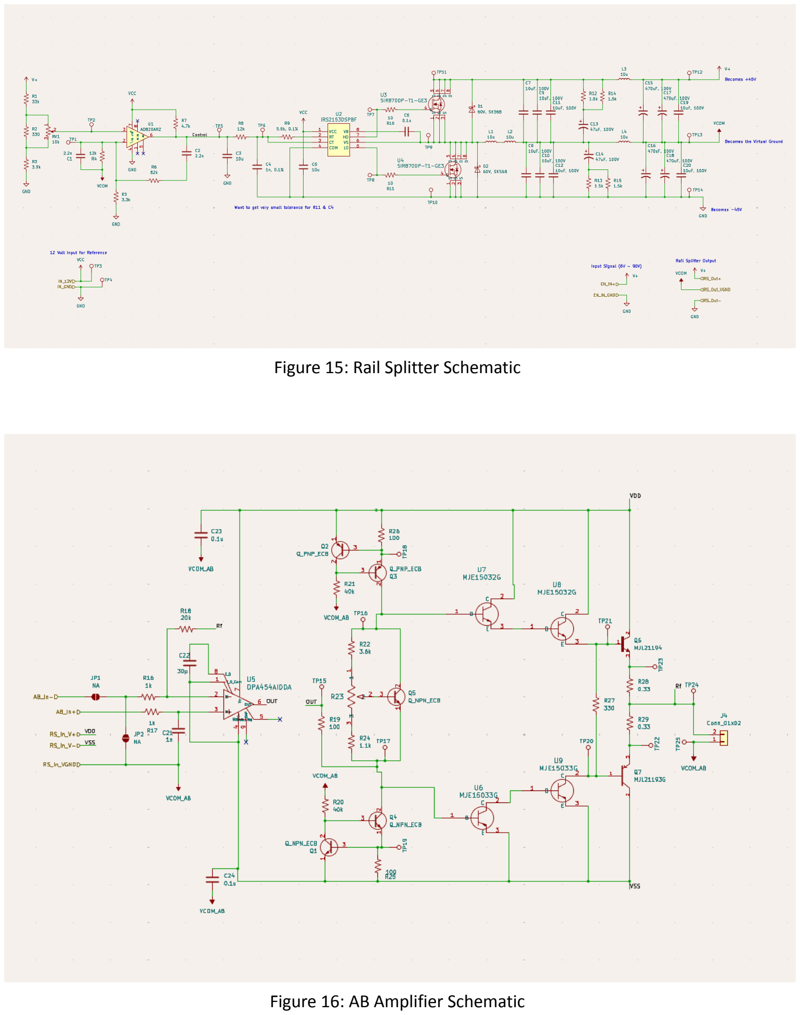
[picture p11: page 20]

Figure 15: Rail Splitter Schematic

Figure 16: AB Amplifier Schematic

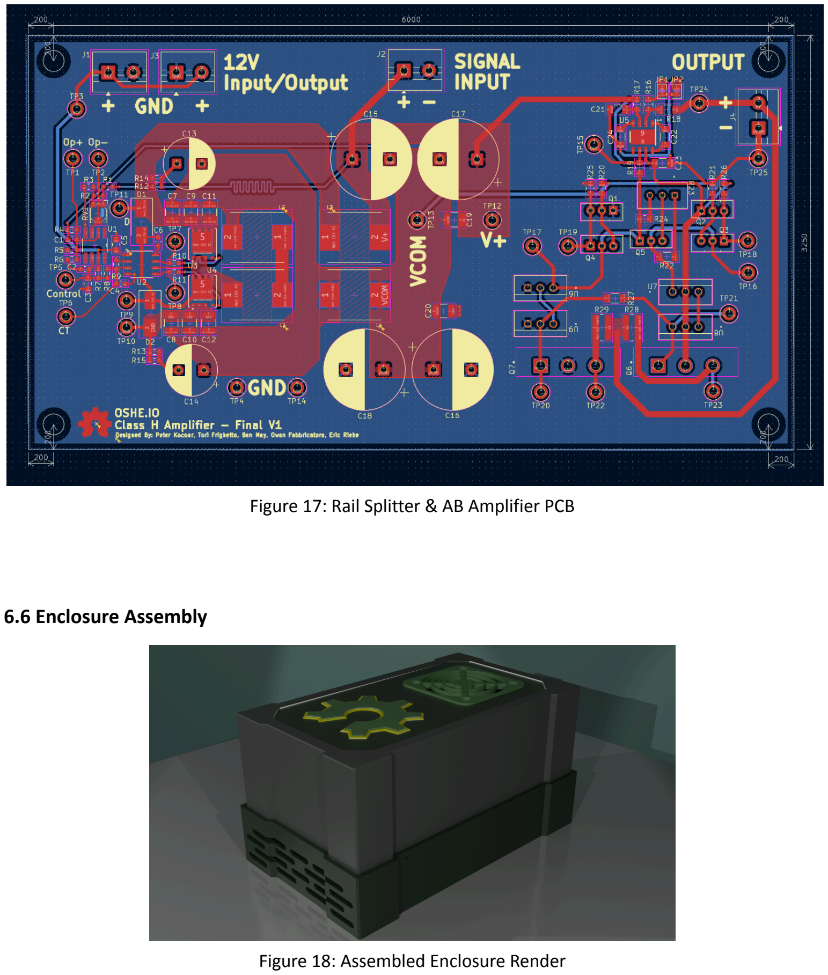
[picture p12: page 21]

Figure 17: Rail Splitter & AB Amplifier PCB

### 6.6 Enclosure Assembly

Figure 18: Assembled Enclosure Render

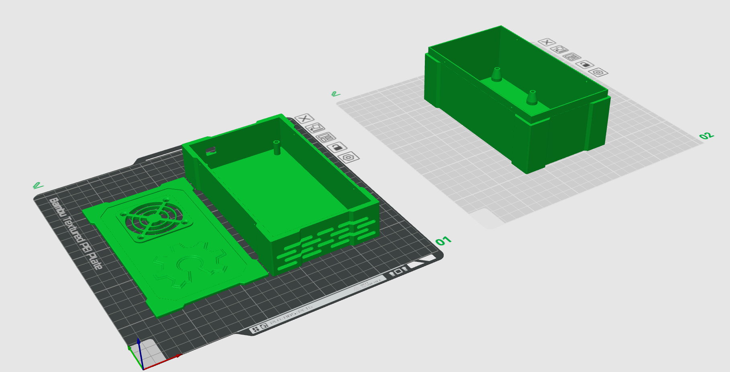
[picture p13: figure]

Figure 19: Printing Plate Layout The enclosure for the Class-H amplifier consists of three distinct parts: The bottom piece, (second from left, figure above) the middle piece (printed upside down, right in figure above), and the top piece (left, figure above.)

The bottom and middle pieces are carefully designed to fit perfectly together, with a tolerance of 0.1mm. If your printer cannot handle this tolerance, it is recommended to scale the middle piece on all axes slightly to ensure a good fit.

### 6.6.1 Enclosure 3D Printing

It is recommended to use the default print settings for all pieces. However, in testing it was found that 5% infill of any shape worked best, and ironing specifically for the top piece helped enhance the quality of the print. The layout shown above is the best, and rotating any of the pieces is not recommended. The size of the build plate in the image is 256mm³

, but it may be printed on as small as 180mm³ ,with each
piece being on its own plate.

### 6.6.2 Enclosure Assembly

To assemble the enclosure you will need the times listed in Table 6.

The #2 x 1/4" Pan Head Sheet Metal Screws are used to connect the rail splitter + AB amplifier board and envelope follower board and to the enclosure on the bottom and top, respectively. They are also used on either side of the enclosure to secure the bottom piece to the middle piece.

The 3mm x 20mm Hex Bolts are used to secure the 50mm x 50mm fan attached to the top of the enclosure. They do not thread in similar to the other screws, and they require nuts attached to the underside of the top piece to secure the fan.

The figure on the left below shows the four mounting holes for the 50mm x 50mm fan and the right image shows the holes for the screws to secure the middle and bottom piece.

### 7. Characterization Data

### 7.1 Protection Simulations

For the protection of the amplifier the LTC4367 IC was used. This allowed for the protection parameters to be set as seen in Table 8. These values were then tested using the LTspice simulation with the out being seen in Figure 15. This figure shows the inputted voltage in green and the voltage supplies to the amplifier in blue. It can be seen that when in reverse bias the voltage is blocked. Also when the voltage is below 12V or above 20V the output voltage is set to 0V. This was the intended result of the protection stage to allow for safe use.

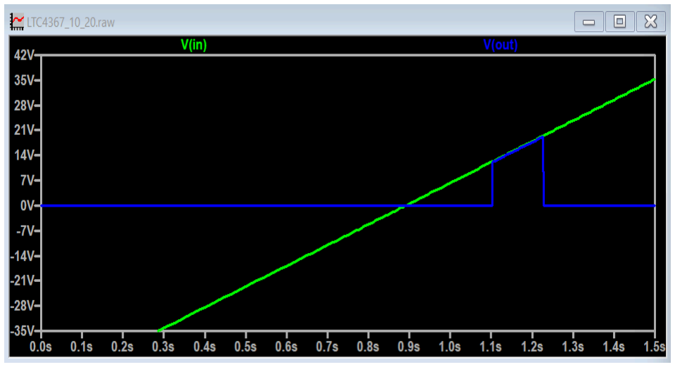
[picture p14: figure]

Figure 20: LTC4367 DC Sweep Simulation

Table 8: Protection Parameters

Protection Type | Protection Parameters
Over Voltage Protection | 20V - 100V

Under Voltage Protection | 0V - 12V
Reverse Polarity | -40V - 0V
Over Current | ATM Mini Fuse

### 7.2 Rail Splitter Simulations

The rail splitter was simulated at various V+ values within the rail splitter’s input voltage range of 12-90
V. At the low end of the range with V+ = 12V, shown in Figure 21, the Vcom value is approximately half the V+ value and that value is shown in Figure 22.

Figure 21. 12V V+

Figure 22. Vcom Value at V+ = 12V

At this input voltage, V+ experiences ripple, which is measured with the recorded value in Figure
23. Figure 24 shows the two waveforms.

Figure 23: V+ Voltage Ripple

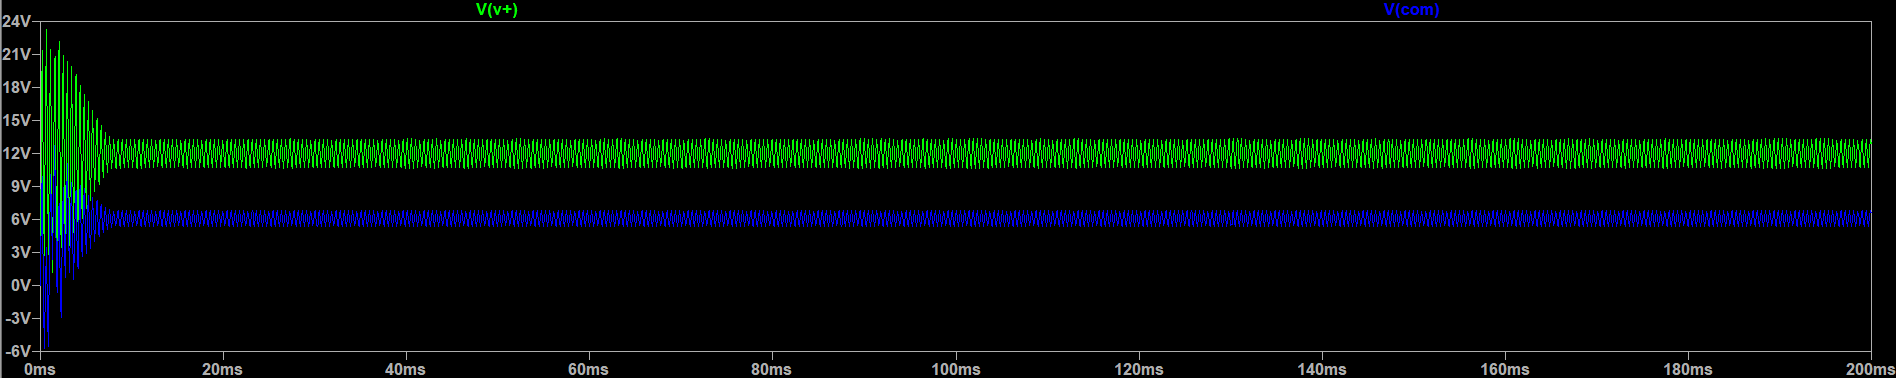
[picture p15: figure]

Figure 24: V+ and Vcom Waveforms at V+ = 12V

The rail splitter functions as expected with a V+ value of 40V, shown in Figure 25. The Vcom value is again approximately half the V+ value and Vcom’s average voltage measurement is seen in Figure 26. Ripple was still present but stayed very close to the same value as the ripple seen with V+ = 12V. Figure 27 shows the waveforms Vcom and V+ with V+ = 40V.

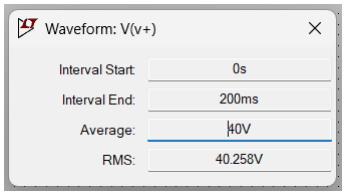
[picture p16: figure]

Figure 25. 40V V+

Figure 26: Vcom

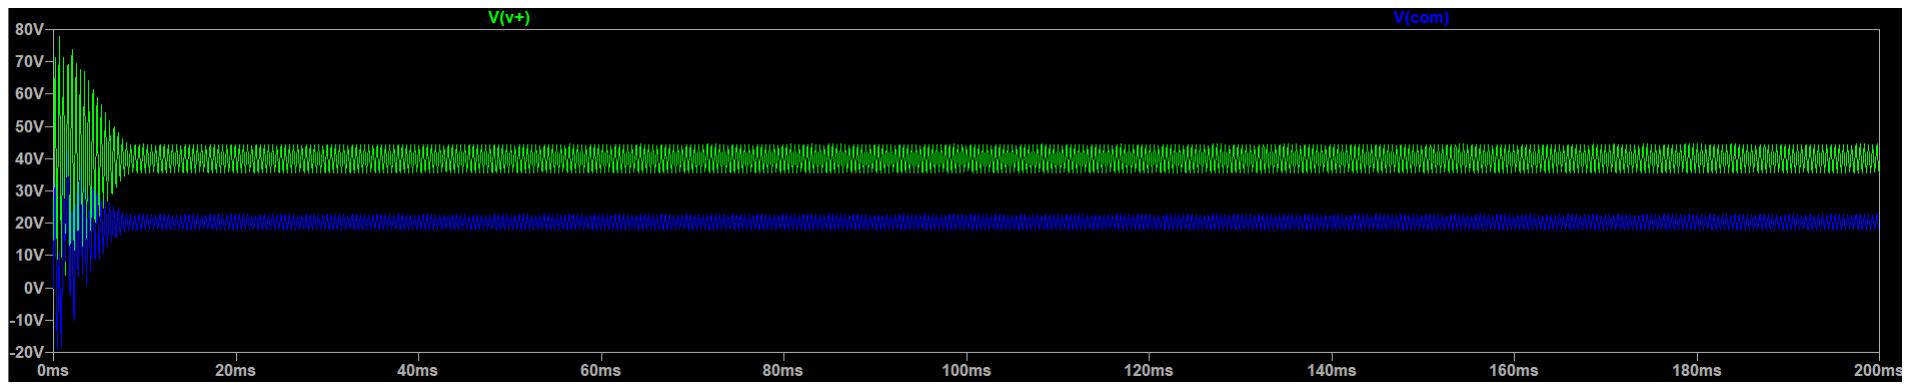
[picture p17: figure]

Figure 27: V+ and Vcom Waveforms at V+ = 40V

The rail splitter also functions as expected at higher values with a V+ value of 84V, shown in Figure 28. The Vcom value is again approximately half the V+ value and Vcom’s average voltage measurement is seen in Figure 24. Ripple did not vary significantly from the values seen at other V+ values. Figure 29 shows the waveforms Vcom and V+ with V+ = 84V.

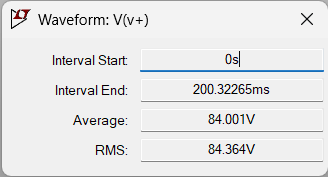
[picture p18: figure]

Figure 28. 84V V+

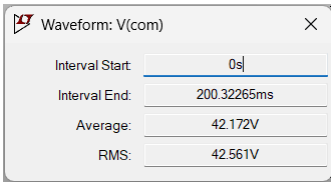
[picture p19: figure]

Figure 29. Vcom Value at V+ = 84V

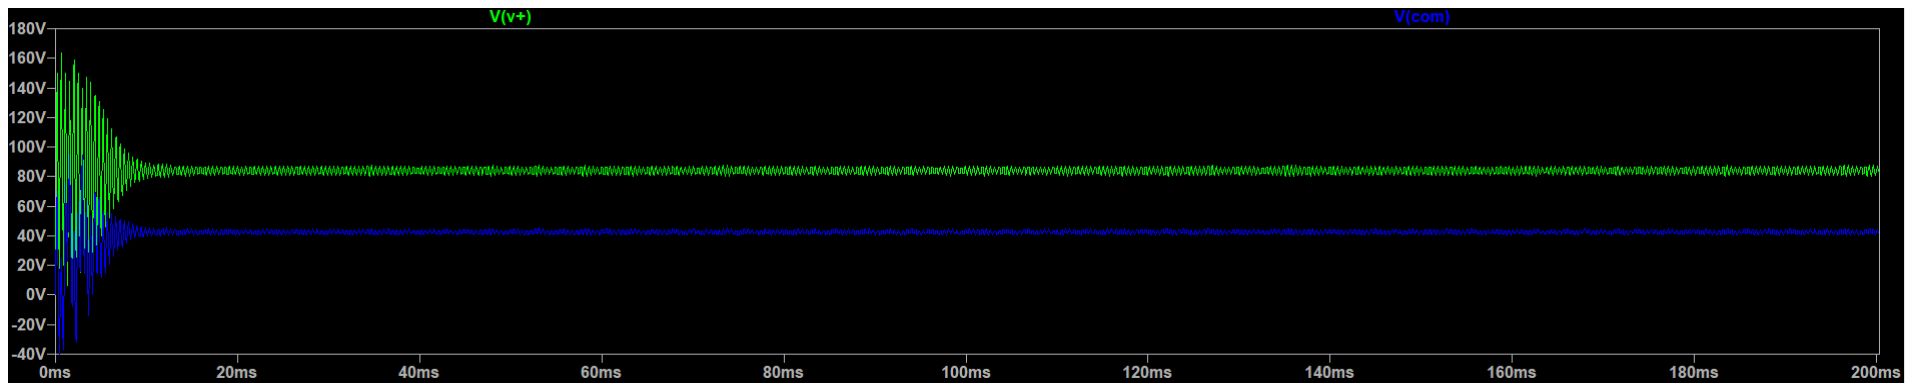
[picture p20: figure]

Figure 30: V+ and Vcom Waveforms at V+ = 84V

At V+ values above 85 V the rail splitter stops functioning properly. With V+ at 90 V, shown in Figure 31 , Vcom is measured at an average of 12.176 V, seen in Figure 32, instead of the expected Vcom value of 45
V. Figure 33 shows the waveforms of the two signals when the rail splitter breaks down.

Figure 32. 90V V+

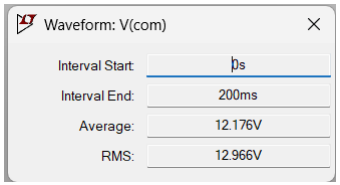
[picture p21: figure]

Figure 33. Vcom Value at V+ = 90V

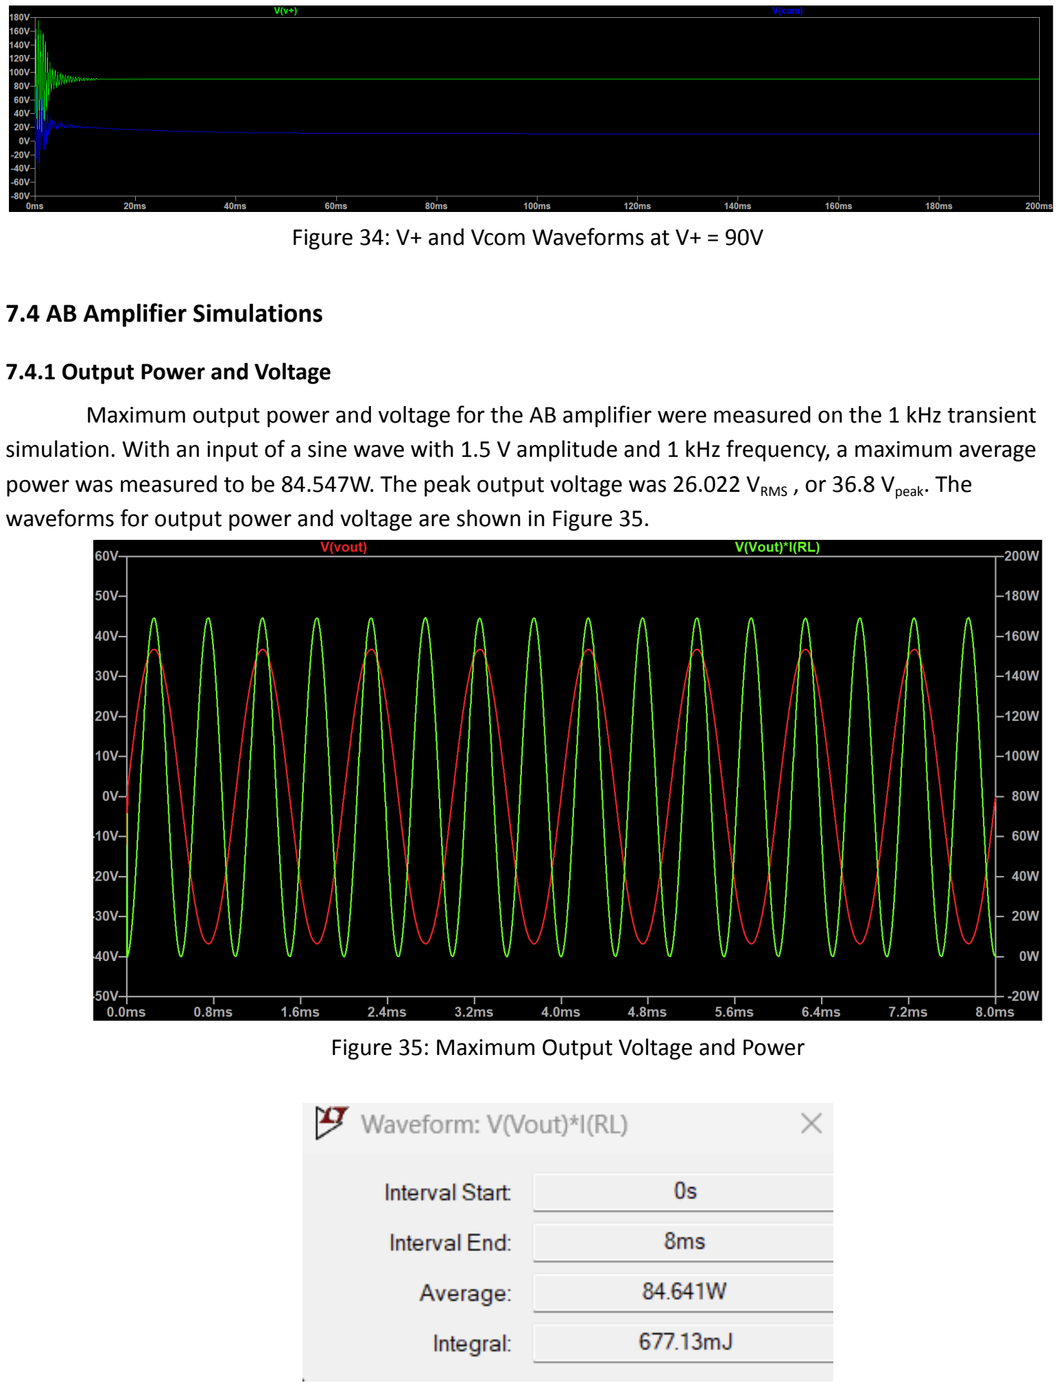
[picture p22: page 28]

Figure 34: V+ and Vcom Waveforms at V+ = 90V

### 7.4 AB Amplifier Simulations

### 7.4.1 Output Power and Voltage

Maximum output power and voltage for the AB amplifier were measured on the 1 kHz transient simulation. With an input of a sine wave with 1.5 V amplitude and 1 kHz frequency, a maximum average power was measured to be 84.547W. The peak output voltage was 26.022 VRMS

, or 36.8 Vpeak

. The
waveforms for output power and voltage are shown in Figure 35.

Figure 35: Maximum Output Voltage and Power

Figure 36: Maximum Output Power Measurement

### 7.4.2 Total Harmonic Distortion

In a transient simulation with a sine wave input of 1 V amplitude and 1 kHz, the FFT of the output was captured as well as the total harmonic distortion calculated by LTspice. The total harmonic distortion calculated was 0.006567%, but this is an idealized case and the actual THD will most likely be greater than this. The THD calculation also appeared to vary with changes in the maximum timestep that is defined in the transient simulation options in LTspice. Figure 37 shows the harmonic components and the THD calculation.

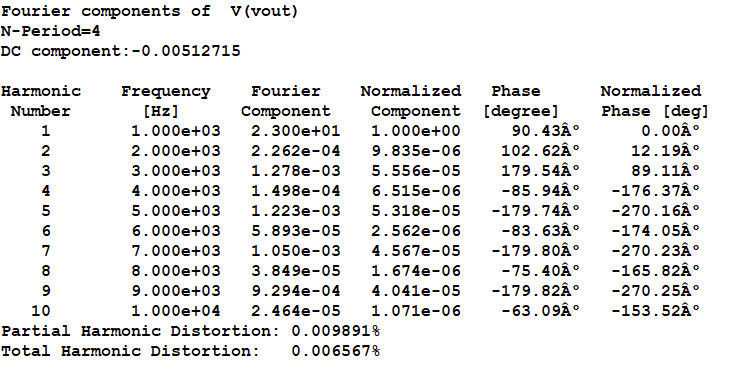
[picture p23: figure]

Figure 37: Total Harmonic Distortion and Fourier Analysis Results in LTSpice

### 7.4.3 Noise and SNR

Figure 38: Total RMS Noise

Figure 39: Noise Measured at Vout of Amplifier The total measured RMS noise at the output in the simulation was 116 μV and the waveform is shown in Figure 39. The signal to noise ratio was calculated using the equation below from [10]

SNR (dB) = 20 × log
10

V
signal,RMS
V
noise,RMS

(7.1)

With a 1 V amplitude input, the calculated SNR was 75.7 dB. The LTspice simulation is an optimistic prediction as it does not consider factors that would occur in the environment.

### 7.4.4 Frequency Response

The frequency response was measured using an AC Analysis simulation with a decade sweep starting at 20 Hz and ending at 1 MHz. The result is shown in Figure 40. The -3 dB point was at about 81 kHz, seen in Figure 41, meaning the frequency response is 20Hz to 81 kHz.

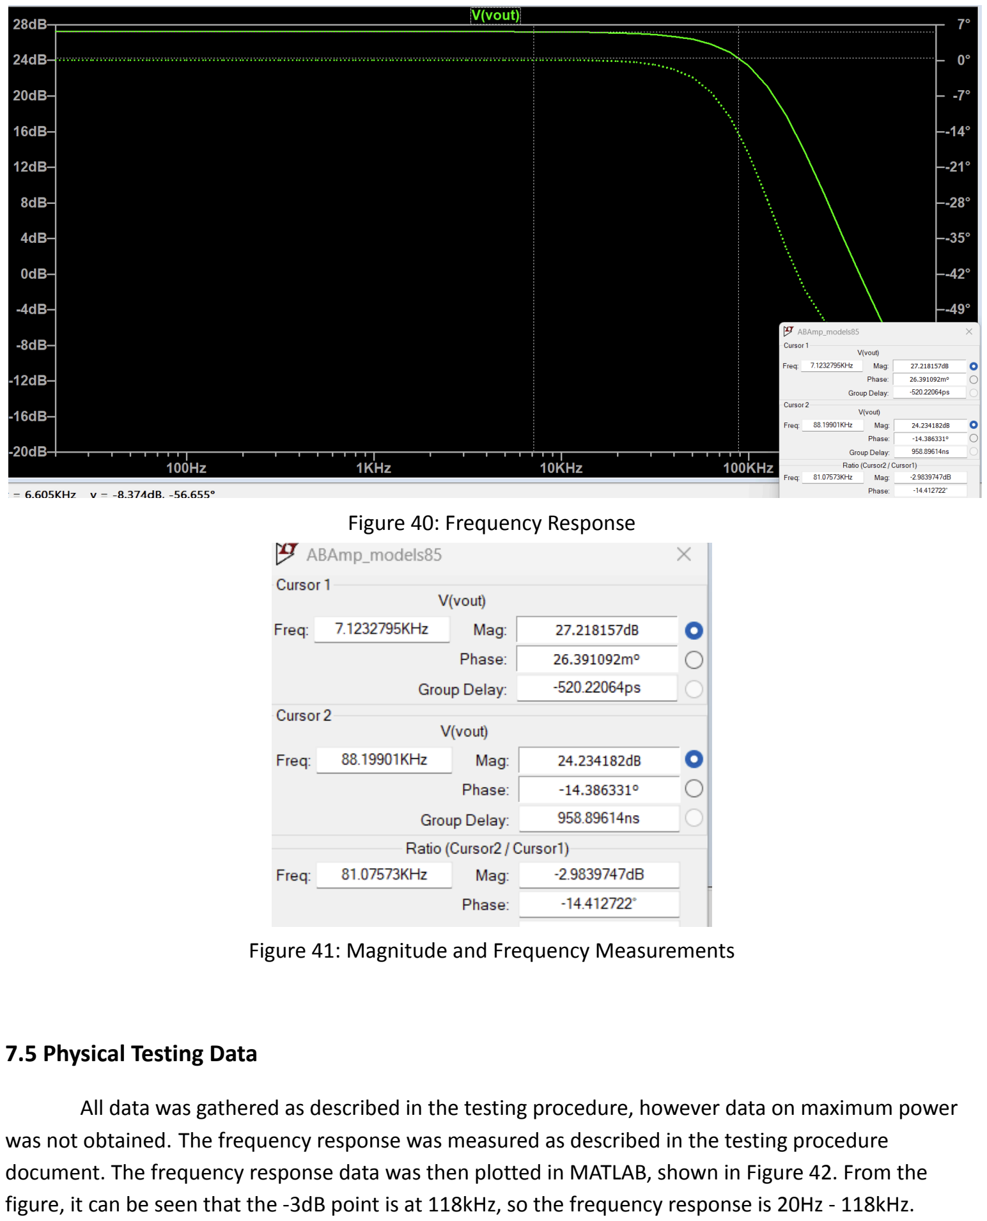
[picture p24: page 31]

Figure 40: Frequency Response

Figure 41: Magnitude and Frequency Measurements

### 7.5 Physical Testing Data

All data was gathered as described in the testing procedure, however data on maximum power was not obtained. The frequency response was measured as described in the testing procedure document. The frequency response data was then plotted in MATLAB, shown in Figure 42. From the figure, it can be seen that the -3dB point is at 118kHz, so the frequency response is 20Hz - 118kHz.

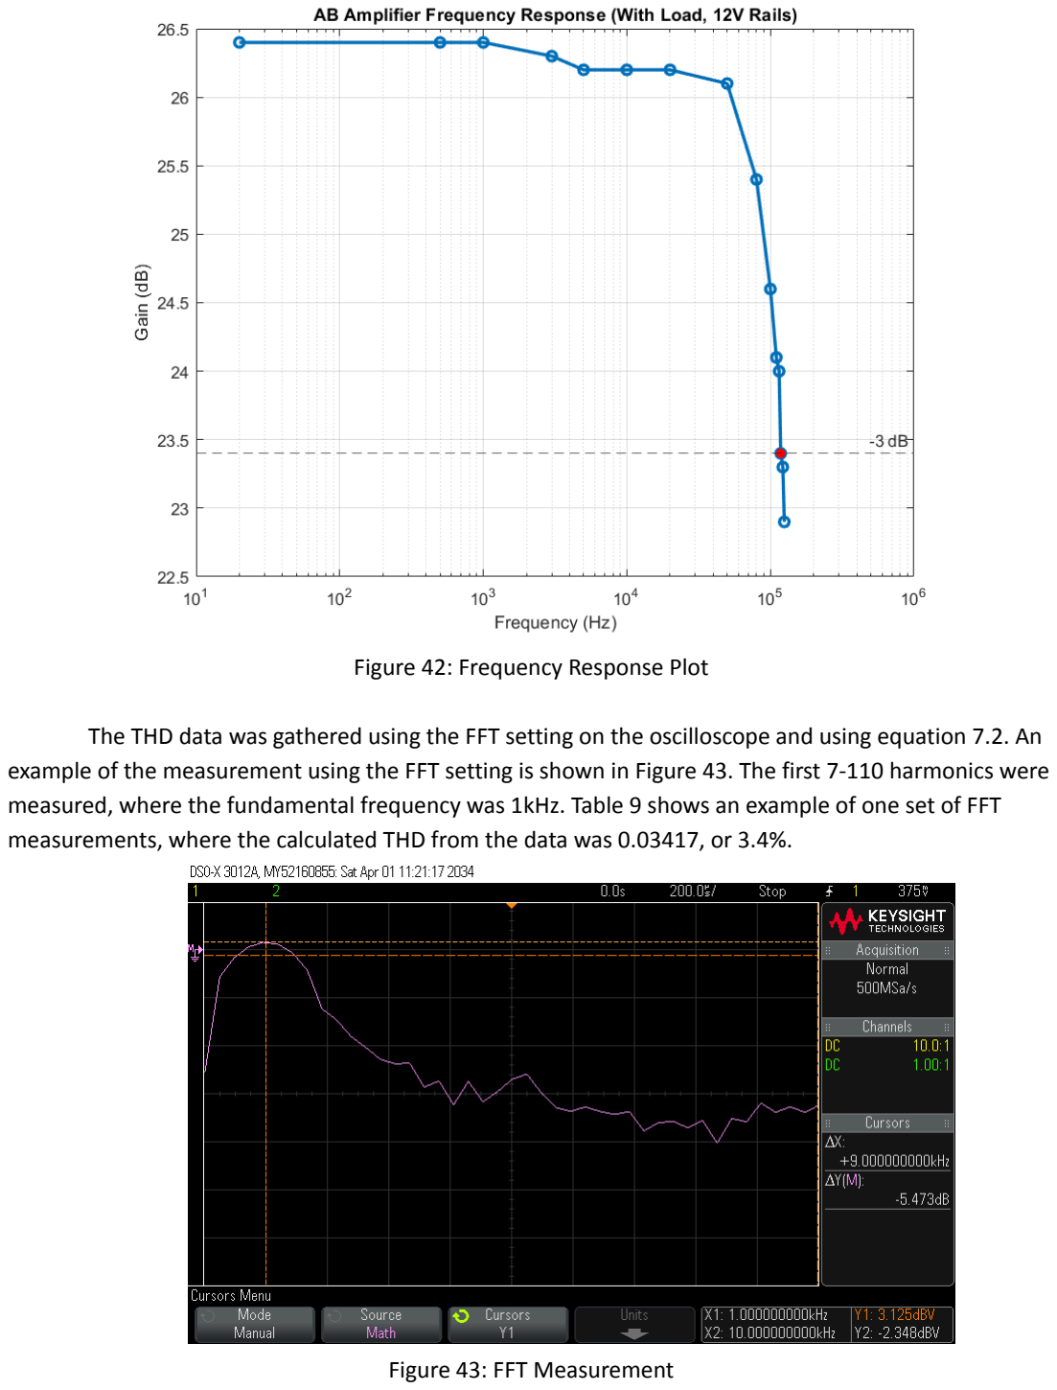
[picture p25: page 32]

Figure 42: Frequency Response Plot

The THD data was gathered using the FFT setting on the oscilloscope and using equation 7.2. An example of the measurement using the FFT setting is shown in Figure 43. The first 7-110 harmonics were measured, where the fundamental frequency was 1kHz. Table 9 shows an example of one set of FFT measurements, where the calculated THD from the data was 0.03417, or 3.4%.

Figure 43: FFT Measurement

THD =

V
2

2+V
3

2+V
4

2+...+V
n

2

V
1

(7.2)

Table 9: THD Harmonics with 8Ω Load, 0.25Vpp 1kHz Sine, ±10V rails

Harmonic | dBV | VRMS
1 | 3.125 | 1.43301257
2 | -26.25 | 0.04869675252
3 | -46.875 | 0.004531583638
4 | -61.25 | 0.0008659643234
5 | -53.75 | 0.002053525026
6 | -66.875 | 0.0004531583638
7 | -70.625 | 0.0002942727176

The SNR measurement was 53.5dB without a load and 55.01dB with a load. These measurements were taken at small inputs where no clipping was present. Additional testing should be done with a larger input.

### 8. Sponsors/Acknowledgements

Our project is not currently sponsored.

### 9. Standards

Open Source Hardware Standards [12]:
1. Documentation
2. Scope
3. Necessary Software
4. Derived Works
5. Free Redistribution
6. Attribution
7. No Discrimination Against Persons or Groups
8. No Discrimination Against Fields of Endeavor
9. Distribution of License
10. License Must Not Be Specific to a Product
11. License Must Not Restrict Other Hardware or Software
12. License Must Be Technology-Neutral

### 10. Recommendations for Future Work

Further testing is required for the final rendition of the rail follower board separately and the combination of the rail follower, rail splitter, and AB amplifier. Results gathered while testing the rail splitter and AB amplifier indicate that distortion can be improved, potentially through edits of the rail follower board as there was noticeable ringing during operation. The current device was not able to be tested up to its maximum output due to limitations on available equipment, so further testing is needed for that to understand its maximum load conditions and how those can be improved. Additional testing with distortion using more precise equipment or measurement techniques can give a more accurate measurement. Finally, the addition of heat sinks could further improve the thermal management.

### 11. References

[1] N. Utomo et al., “An 85.1% Peak Efficiency, Low Power Class H Audio Amplifier With Full Class H Operation,” IEEE transactions on circuits and systems. I, Regular papers, vol. 70, no. 12, pp. 1–13, 2023, doi: 10.1109/TCSI.2023.3305622.
[2] S. Munz, “Slew Rate in Audio Amplifiers - What Does it Mean?,” Audioholics, Feb. 08, 2013. https://www.audioholics.com/audio-amplifier/amplifier-slew-rate
[3] “Cambridge Audio,” Cambridge Audio. https://www.cambridgeaudio.com/usa/en/blog/amplifier-specifications

[4] “What is Total Harmonic Distortion (THD)?,” Audiophile On, Aug. 16, 2025. https://www.google.com/url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
[5] V. Batra, “Modular Concepts: What is an Envelope Follower?,” Perfect Circuit, Aug. 22, 2024. https://www.perfectcircuit.com/signal/envelope-followers
[6] “What’s the difference between MOSFET and BJT and how to choose?,” NextPCB. https://www.nextpcb.com/blog/what-is-the-difference-between-mosfet-and-bjt-and-how-to-choose
[7] A. Sedra and K. Smith, Microelectronic Circuits. S.L.: Oxford Univ Press US, 2019.
[8] O. Jørgensen, “What do different amplifier classes mean?,” Dynaudio.com, May 14, 2025. https://dynaudio.com/magazine/2025/may/amplifier-classes-ask-the-expert
[9] D. Self, Audio Power Amplifier Design, Sixth. Burlington ; Oxford: Elsevier / Focal Press, 2013.
[10] Cadence PCB Solutions, “What is Signal to Noise Ratio and How to calculate it?,” resources.pcb.cadence.com, 2023. https://resources.pcb.cadence.com/blog/2020-what-is-signal-to-noise-ratio-and-how-to-calculate-it [12]“OSHW,” Freedomdefined.org, 2023. https://freedomdefined.org/OSHW

This was also used as a general reference for various amplifier topics and designs that were not directly referenced in this report:
[13] B. Cordell, Designing Audio Power Amplifiers. McGraw Hill Professional, 2010.

### 12. Appendix

## CHECKLIST FOR PROJECTS ENT 4950/60

A copy of this checklist must be submitted with the project report.

### ABET Requirement:

### 1. Have you reviewed relevant industry standard(s) pertaining to your project and applied the necessary ones?

### Yes ☑

### 2. Have you included a list of the standards used in project documentation? Where: Section 9 of the Class H Report

### Yes ☑

3. Has your design considered public health, safety, and welfare | Yes ☑ | Not Applicable ☐

### 4. Has your design/solution considered the following factors:

a. global factors | Yes ☑ | Not Applicable ☐
b. cultural factors | Yes ☑ | Not Applicable ☐
c. social factors | Yes ☑ | Not Applicable ☐
d. environmental factors | Yes ☑ | Not Applicable ☐
e. economic factors | Yes ☑ | Not Applicable ☐

### Project work

### 1. Does the report have a one page Executive Summary that can be

read on its own? | Yes ☑ | No ☐
2. Does you project report have a clear problem statement | Yes ☑ | No ☐

### 3. If this is a continuation from a previous semester/ year, is the

previous work described appropriately in the report? | Yes ☑ | No ☐

### 4. Have you described the relevant constraints to your

design/solution? | Yes ☑ | No ☐

### 5. Have you documented the different design options considered

before arriving at the final design/solution? | Yes ☑ | No ☐

6. Have you included recommendations for future work | Yes ☑ | No ☐

### Project Sponsor

### 1. Have you received explicit permission from your sponsor to share

details about the project or client? | Yes ☑ | No ☐

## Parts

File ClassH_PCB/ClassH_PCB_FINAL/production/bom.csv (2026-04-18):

Designator | Footprint | Quantity | Value | LCSC Part #
C1, C2 | 0603 | 2 | 2.2n
C10, C11, C12, C19, C20, C7, C8, C9 | 1210 | 8 | 10uF, 100V
C13, C14 | CP_Radial_D10.0mm_P5.00mm | 2 | 47uF, 100V
C15, C16, C17, C18 | CP_Radial_D16.0mm_P7.50mm | 4 | 470uF, 100V
C21 | 1206 | 1 | 1n
C22 | 1206 | 1 | 30p
C23, C24 | 1206 | 2 | 0.1u
C3, C5 | 0805 | 2 | 10u
C4 | 0603 | 1 | 1n, 0.1%
C6 | 0603 | 1 | 0.1u
D1, D2 | D_SMB_Handsoldering | 2 | 60V, SK56B
J1, J2, J3, J4 | TerminalBlock_MaiXu_MX126-5.0-02P_1x02_P5.00mm | 4 | Conn_01x02
L1, L2, L3, L4 | IND_ETQP5M100YFC | 4 | 10u
Q1, Q4, Q5 | TO-126-3_Vertical | 3 | Q_NPN_ECB
Q2, Q3 | TO-126-3_Vertical | 2 | Q_PNP_ECB
Q6 | TO545P2030X530X2900-3 | 1 | MJL21194
Q7 | TO545P2030X530X2900-3 | 1 | MJL21193G
R1 | 0603 | 1 | 33k
R10, R11 | 0603 | 2 | 10
R12, R13, R14, R15 | 0603 | 4 | 1.5k
R16, R17 | 0805 | 2 | 1k
R18 | 1206 | 1 | 20k
R19, R25, R26 | 0805 | 3 | 100
R2 | 0603 | 1 | 330
R20, R21 | 0805 | 2 | 40k
R22 | 1206 | 1 | 3.6k
R23 | POT_PV36W_MUR | 1 | PV36W102C01B00
R24 | 0805 | 1 | 1.1k
R27 | 1206 | 1 | 330
R28, R29 | 1020 | 2 | 0.33
R3 | 0603 | 1 | 3.9k
R4, R8 | 0603 | 2 | 12k
R5 | 0603 | 1 | 3.3k
R6 | 0603 | 1 | 82k
R7 | 0603 | 1 | 4.7k
R9 | 0603 | 1 | 5.6k, 0.1%
RV1 | Potentiometer_Bourns_TC33X_Vertical | 1 | 10k
TP1, TP10, TP11, TP12, TP13, TP14, TP15, TP16, TP17, TP18, TP19, TP2, TP20, TP21, TP22, TP23, TP24, TP25, TP3, TP4, TP5, TP6, TP7, TP8, TP9 | TestPoint_Keystone_5005-5009_Compact | 25 | TestPoint
U1 | SOIC127P600X175-8N | 1 | AD820ARZ | AD820ARZ-REEL-REEL7
U2 | SOIC8_INF | 1 | IRS2153DSPBF
U3, U4 | MOSFET_7DP-T1-GE3_VIS | 2 | SIR870DP-T1-GE3
U5 | DDA0008J_NV | 1 | OPA454AIDDA
U6, U9 | TO-220AB_ONS | 2 | MJE15033G
U7, U8 | TO-220AB_ONS | 2 | MJE15032G

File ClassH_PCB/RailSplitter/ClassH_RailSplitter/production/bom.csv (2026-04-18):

Designator | Footprint | Quantity | Value | LCSC Part #
C1, C2 | 0603 | 2 | 2.2n
C10, C11, C12, C19, C20, C7, C8, C9 | 1210 | 8 | 10uF, 100V
C13, C14 | CP_Radial_D10.0mm_P5.00mm | 2 | 47uF, 100V
C15, C16, C17, C18 | CP_Radial_D16.0mm_P7.50mm | 4 | 470uF, 100V
C3, C5 | 0805 | 2 | 10u
C4 | 0603 | 1 | 1n, 0.1%
C6 | 0603 | 1 | 0.1u
D1, D2 | D_SMB_Handsoldering | 2 | 60V, SK56B
J1 | TerminalBlock_MaiXu_MX126-5.0-02P_1x02_P5.00mm | 1 | Conn_01x02
J2, J3, J4 | MountingHole_5mm_Pad_TopBottom | 3 | Conn_01x01
L1, L2, L3, L4 | IND_ETQP5M100YFC | 4 | 10u
R1 | 0603 | 1 | 33k
R10, R11 | 0603 | 2 | 10
R12, R13, R14, R15 | 0603 | 4 | 1.5k
R2 | 0603 | 1 | 330
R3 | 0603 | 1 | 3.9k
R4, R8 | 0603 | 2 | 12k
R5 | 0603 | 1 | 3.3k
R6 | 0603 | 1 | 82k
R7 | 0603 | 1 | 4.7k
R9 | 0603 | 1 | 5.6k, 0.1%
RV1 | Potentiometer_Bourns_TC33X_Vertical | 1 | 10k
TP1, TP10, TP11, TP12, TP13, TP2, TP3, TP4, TP5, TP6, TP7, TP8, TP9 | TestPoint_Keystone_5005-5009_Compact | 13 | TestPoint
U1 | SOIC127P600X175-8N | 1 | AD820ARZ | AD820ARZ-REEL-REEL7
U2 | SOIC8_INF | 1 | IRS2153DSPBF
U3, U4 | MOSFET_7DP-T1-GE3_VIS | 2 | SIR870DP-T1-GE3

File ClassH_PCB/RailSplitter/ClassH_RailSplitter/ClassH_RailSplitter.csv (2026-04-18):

Reference | Qty | Value | DNP | Exclude from BOM | Exclude from Board | Footprint | Datasheet
C1,C2 | 2 | 2.2n |  |  |  | Capacitor_SMD:C_0603_1608Metric_Pad1.08x0.95mm_HandSolder | ~
C3,C5 | 2 | 10u |  |  |  | Capacitor_SMD:C_0805_2012Metric_Pad1.18x1.45mm_HandSolder | ~
C4 | 1 | 1n, 0.1% |  |  |  | Capacitor_SMD:C_0603_1608Metric_Pad1.08x0.95mm_HandSolder | ~
C6 | 1 | 0.1u |  |  |  | Capacitor_SMD:C_0603_1608Metric_Pad1.08x0.95mm_HandSolder | ~
C7,C8,C9,C10,C11,C12,C19,C20 | 8 | 10uF, 100V |  |  |  | Capacitor_SMD:C_1210_3225Metric_Pad1.33x2.70mm_HandSolder | ~
C13,C14 | 2 | 47uF, 100V |  |  |  | Capacitor_THT:CP_Radial_D10.0mm_P5.00mm | ~
C15,C16,C17,C18 | 4 | 470uF, 100V |  |  |  | Capacitor_THT:CP_Radial_D16.0mm_P7.50mm | ~
D1,D2 | 2 | 60V, SK56B |  |  |  | Diode_SMD:D_SMB_Handsoldering | ~
J1 | 1 | Conn_01x02 |  |  |  | TerminalBlock:TerminalBlock_MaiXu_MX126-5.0-02P_1x02_P5.00mm | ~
J2,J3,J4 | 3 | Conn_01x01 |  |  |  | MountingHole:MountingHole_5mm_Pad_TopBottom | ~
L1,L2,L3,L4 | 4 | 10u |  |  |  | ClassH_Footprint_Library:IND_ETQP5M100YFC | ~
R1 | 1 | 33k |  |  |  | Resistor_SMD:R_0603_1608Metric_Pad0.98x0.95mm_HandSolder | ~
R2 | 1 | 330 |  |  |  | Resistor_SMD:R_0603_1608Metric_Pad0.98x0.95mm_HandSolder | ~
R3 | 1 | 3.9k |  |  |  | Resistor_SMD:R_0603_1608Metric_Pad0.98x0.95mm_HandSolder | ~
R4,R8 | 2 | 12k |  |  |  | Resistor_SMD:R_0603_1608Metric_Pad0.98x0.95mm_HandSolder | ~
R5 | 1 | 3.3k |  |  |  | Resistor_SMD:R_0603_1608Metric_Pad0.98x0.95mm_HandSolder | ~
R6 | 1 | 82k |  |  |  | Resistor_SMD:R_0603_1608Metric_Pad0.98x0.95mm_HandSolder | ~
R7 | 1 | 4.7k |  |  |  | Resistor_SMD:R_0603_1608Metric_Pad0.98x0.95mm_HandSolder | ~
R9 | 1 | 5.6k, 0.1% |  |  |  | Resistor_SMD:R_0603_1608Metric_Pad0.98x0.95mm_HandSolder | ~
R10,R11 | 2 | 10 |  |  |  | Resistor_SMD:R_0603_1608Metric_Pad0.98x0.95mm_HandSolder | ~
R12,R13,R14,R15 | 4 | 1.5k |  |  |  | Resistor_SMD:R_0603_1608Metric_Pad0.98x0.95mm_HandSolder | ~
RV1 | 1 | 10k |  |  |  | Potentiometer_SMD:Potentiometer_Bourns_TC33X_Vertical | ~
TP1,TP2,TP3,TP4,TP5,TP6,TP7,TP8,TP9,TP10,TP11,TP12,TP13 | 13 | TestPoint |  |  |  | TestPoint:TestPoint_Keystone_5005-5009_Compact | ~
U1 | 1 | AD820ARZ |  |  |  | ClassH_Footprint_Library:SOIC127P600X175-8N
U2 | 1 | IRS2153DSPBF |  |  |  | ClassH_Footprint_Library:SOIC8_INF | https://www.infineon.com/dgdl/irs2153d.pdf?fileId=5546d462533600a401535676951e27c3
U3,U4 | 2 | SIR870DP-T1-GE3 |  |  |  | ClassH_Footprint_Library:MOSFET_7DP-T1-GE3_VIS | https://www.vishay.com/doc?67197

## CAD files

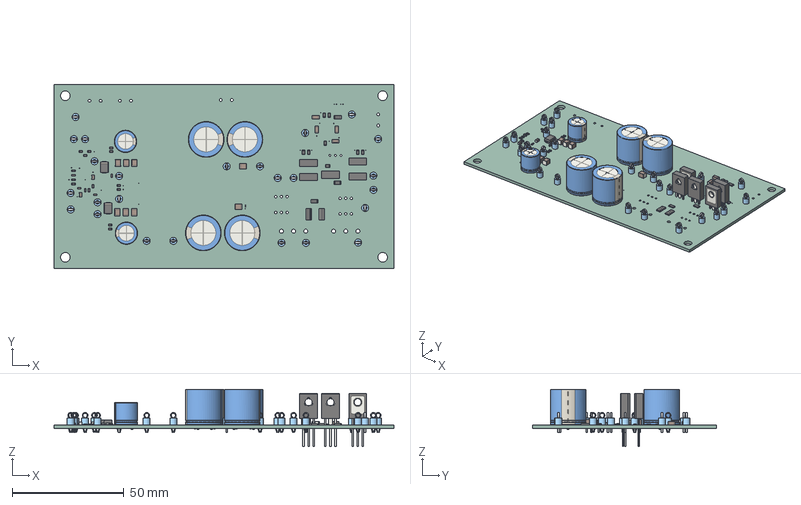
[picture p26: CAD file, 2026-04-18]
ClassH_PCB/ClassH_PCB_FINAL/ClassH_PCB_FINAL.step
152.4 x 82.6 x 25.8 mm
TO-126-3_Vertical x 5
TestPoint_Keystone_5005-5009_Compact x 25
C_1206_3216Metric x 4
C_1210_3225Metric x 8
R_0603_1608Metric x 15
C_0603_1608Metric x 4
R_0805_2012Metric x 8
D_SMB x 2
CP_Radial_D16.0mm_P7.50mm x 4
R_1206_3216Metric x 3
C_0805_2012Metric x 2
R_1020_2550Metric x 2
CP_Radial_D10.0mm_P5.00mm x 2
ClassH_PCB_FINAL_PCB

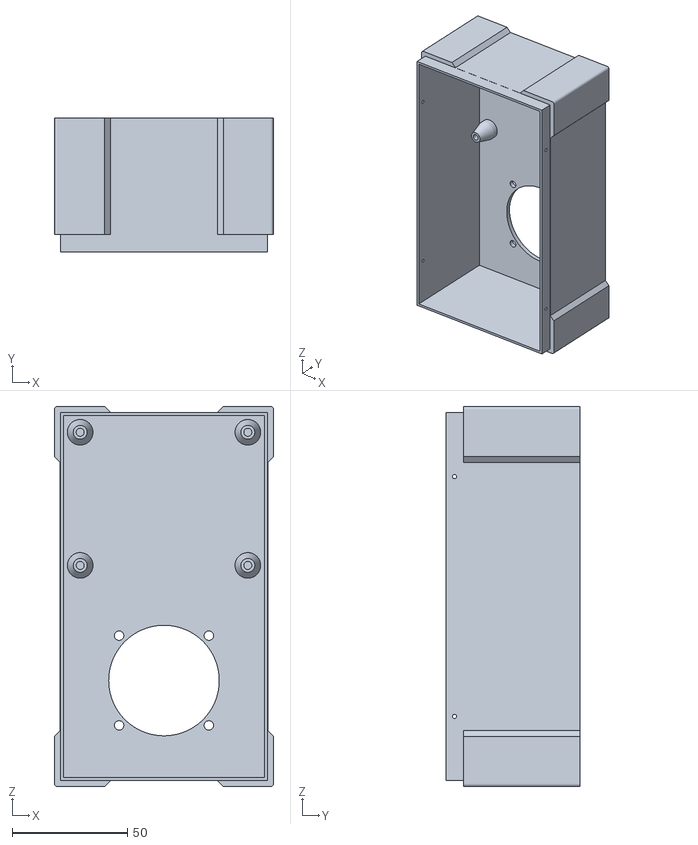
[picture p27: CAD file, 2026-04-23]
Enclosure/OSHE_ClassH_Enclosure_v2.0_mid.stl
95.2 x 58.4 x 165.1

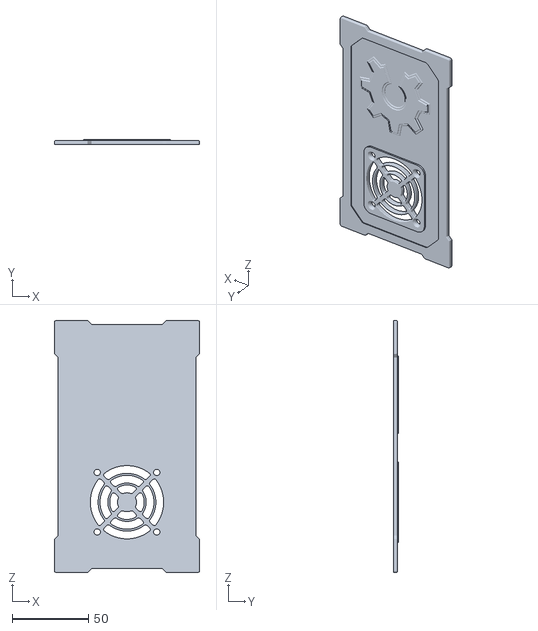
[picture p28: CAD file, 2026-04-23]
Enclosure/OSHE_ClassH_Enclosure_v2.0_top.stl
95.2 x 3.17 x 165.1

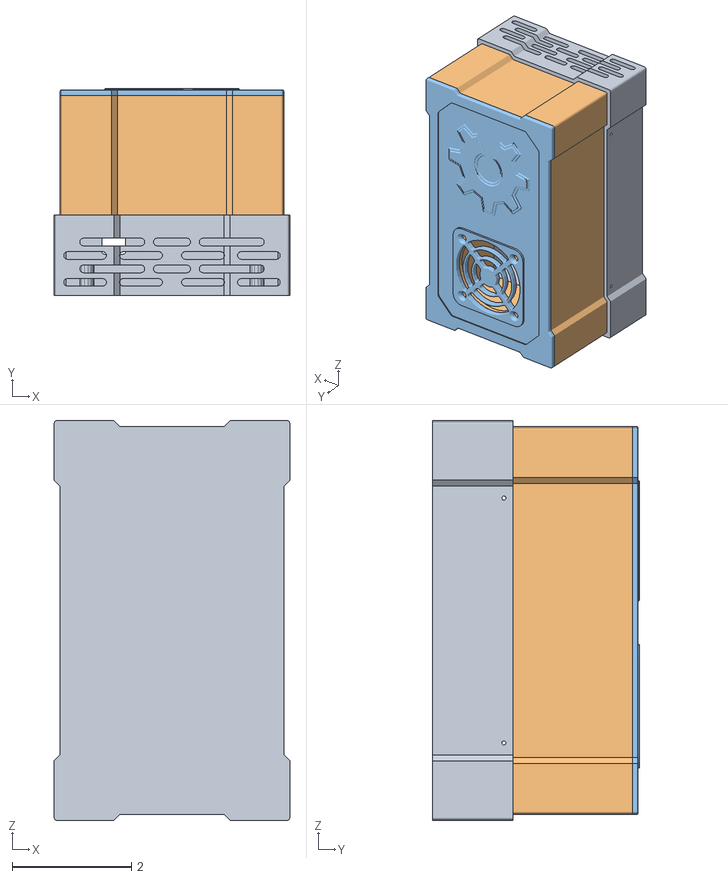
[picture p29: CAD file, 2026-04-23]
Enclosure/OSHE_ClassH_Enclosure_v2.0.obj
3.95 x 3.48 x 6.70

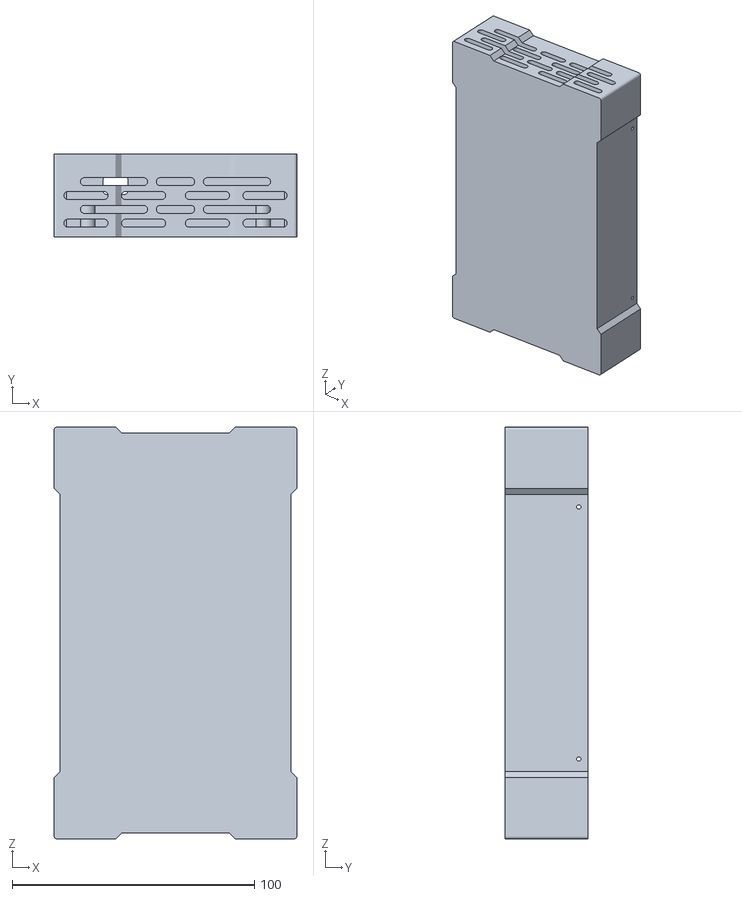
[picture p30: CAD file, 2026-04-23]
Enclosure/OSHE_ClassH_Enclosure_v2.0_bottom.stl
100.3 x 34.3 x 170.2

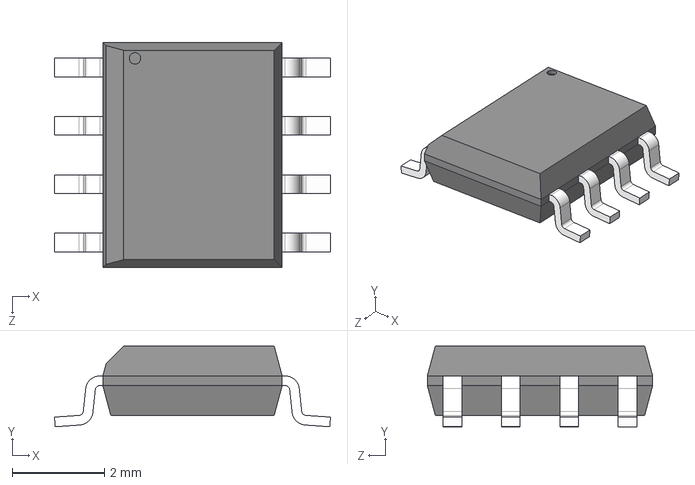
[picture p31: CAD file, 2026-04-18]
ClassH_PCB/Digikey_Models/AD820ARZ/AD820ARZ-REEL-REEL7.step
6.00 x 1.75 x 4.90 mm

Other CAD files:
Enclosure/OSHE_ClassH_Enclosure_v2.0.ipt

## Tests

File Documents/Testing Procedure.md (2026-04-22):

# Testing Procedure
This guide provides a general outline of how testing should occur for the rail splitter, AB amplifier, and combination of the rail splitter and AB amplifier PCBs. 
The steps may vary depending on any modifications to the PCBs. No guide has been written for the rail follower at this point in time.

## Rail Splitter

### Setup
Prepare a variable DC power supply capable of 1V-95V which will be connected to input (Believed to be silkscreened J1/J3; confirm at meeting tmr)
Prepare an oscilloscope with standard probes and differential probe
Get a thermal camera

### Procedure
Connect the variable DC power supply to the main power input terminals, set to 1.0V with a strict current limit (100mA-500mA) to prevent failure if a short occurs
Connect channel 1 of the oscilloscope to the main control signal input (Probably TP5 or TP6, confirm at meeting)
Connect channel 2 and channel 3 to monitor the high side and the low side gate drive signals. Probe the test points directly next to the stitching ICs/MOSFETS (TP7, TP8, TP9, or TP10)
Connect the differential probe across the output rails of the splitter to measure the ripple
Probe TP12 (V+) and TP13(VCOM) to test the rail
Increase the voltage and check the control signals at the input stage to make sure they are stable
Verify the gate drive signals are clean and free of noise
Measure the ripple at different voltages (20V, 40V, etc.) and record the Vpp

## AB Amplifier

### Power Up
Setup
* Connect fixed supply rails, starting at 0V and slowly increasing
* Grounded input
* No load

1. Start supply rails at 0V and slowly increase to ±15 V
2. Measure quiescent supply current
3. Measure quiescent current at emitter resistors
4. Measure output DC offset with multimeter
5. Observe output on oscilloscope

Expected:
* Vout < 30 mV

### Small Signal Test
1. Apply 1 kHz sine wave, starting at 100mVpp
2. Observe output waveform on oscilloscope
3. Measure output amplitude
4. Vary rail voltage and record where clipping occurs
5. Change input to square wave
6. Check for crossover distortion, noise, etc.

Expected
* Clear sine waveform, clipping may occur at different rail voltages depending on the input
* No crossover distortion
* Minimal noise in square wave

### Frequency Response
Setup
* Fixed rails: ±10V
* Input: Sine wave
* No load, then 8Ω load

1. Apply sine wave with amplitude ~100 mV
2. Adjust input if needed
3. Sweep frequency at least 20 Hz - 20 kHz
4. At each frequency, measure Ratio FS 1->2 (RMS1/RMS2)
5. Calculate gain at each frequency
6. Generate a plot with data

Expected
* Gain around 26dB from 20 Hz to at least 20 kHz
* -3dB drop in gain some point after 20kHz (likely after 80kHz)

### Power Output
1. Set the power supply to ±20 V initially
2. Connect the 8Ω load to the output terminal
3. Apply 1 V amplitude sine wave
4. Gradually increase the power supply up to ± X V
5. Gradually increase amplitude, up to 2V if needed but ~100W should be achieved a little lower than that
6. Measure RMS output voltage on the oscilloscope
7. Measure output current

Expected
* ~100W with ±45 V rails at some input amplitude between XV and XV
* Stability

### Supply Rails
Setup
* Rails at ±15V, ±20V, ±25V, ±30V, ±45V
* Input: Sine wave initially at 1V amplitude
* 8Ω load

1. Set rails to starting level of ±15V
2. Apply sine wave, gradually increasing amplitude like test 3.4
3. Measure output voltage 
4. Record clipping if it occurs
5. Measure output power
6. Repeat for each rail level

Expected
* Clipping at lower rail voltages
* No clipping over 30 V rails

### Thermal
1. Connect the the output of the amplifier to 8Ω load
2. Supply ±V to rails
3. Configure input to sine wave, X Vpp, 1kHz frequency
4. Record temperatures of MJE and MJL transistors  after X minute with thermal camera
5. Repeat for different inputs and rails

### Total Harmonic Distortion
1. Connect the the output of the amplifier to 8Ω load
2. Supply  ±15 to rails
3. Configure input to sine wave, 0.5 Vpp, 1kHz frequency
4. Connect oscilloscope probe to output of amplifier
5. View FFT of output on oscilloscope
6. Use cursors to measure dBV at 1kHz, 2kHz, 3kHz, etc.
7. Record harmonic measurements and convert to VRMS
8. Calculate THD

Expected:
* THD < 5% if signal isn’t clipped
* Higher THD if signal is clipping

### Noise
1. Connect the the output of the amplifier to 8Ω load
2. Supply  ±15  to rails
3. Configure input to sine wave, 0.5 Vpp, 1kHz frequency
4. Select Limit Bandwidth on the oscilloscope
5. Measure RMS output voltage
6. Disconnect input signal
7. Measure RMS output voltage (noise) using AC coupling on oscilloscope
8. Calculate SNR
9. SNR = 20log10VsignalVnoise

Expected:
*SNR > 50 dB
*Noise on order of 3mV

### Efficiency
1. Measure supply power 
2. Measure output voltage (RMS)
3. Calculate output power:
		Pout= Vout(RMS)2/8 
4. Calculate input power:
    Pin= V+I++|V-||I-|
5. Calculate efficiency

## Rail Splitter and AB Amplifier Board

### Start Up
1. Set the DC power supply to 12 V
2. Set another power supply to 20V initially
3. Connect the 12 V supply to the + and GND terminals labeled 12V Input/Output
4. Connect the 20V supply to the + and - terminals labeled POWER INPUT
5. Connect an oscilloscope probe to the + of the OUTPUT terminal through the testpoint TP24 and connect the ground of the probe to TP25 (OUTPUT -).
6. Power on both power supplies
7. Observe the current draw from the supplies, very low current is expected (0.01 - 0.02 Amps)

### Low Rails, No Load
1. Keep the same setup as test 4.1, but additionally configure a signal generator to output a sine wave with 250 mVpp and 1kHz frequency
2. Connect the signal generator output to board
3. Turn on the power supplies
4. Turn on the output of the signal generator
5. Observe the current on the power supplies, it should still remain relatively low (<0.1A)
6. Lower the power supply for the rails until the output waveform no longer clips (~13-14V)
7. Measure the peak-to-peak voltage of the output waveform

## Full Class H Amplifier
Testing procedure will be similar to that of the AB amplifier but with differences in input connections. Details are not present due to lack of testing at this point in time.

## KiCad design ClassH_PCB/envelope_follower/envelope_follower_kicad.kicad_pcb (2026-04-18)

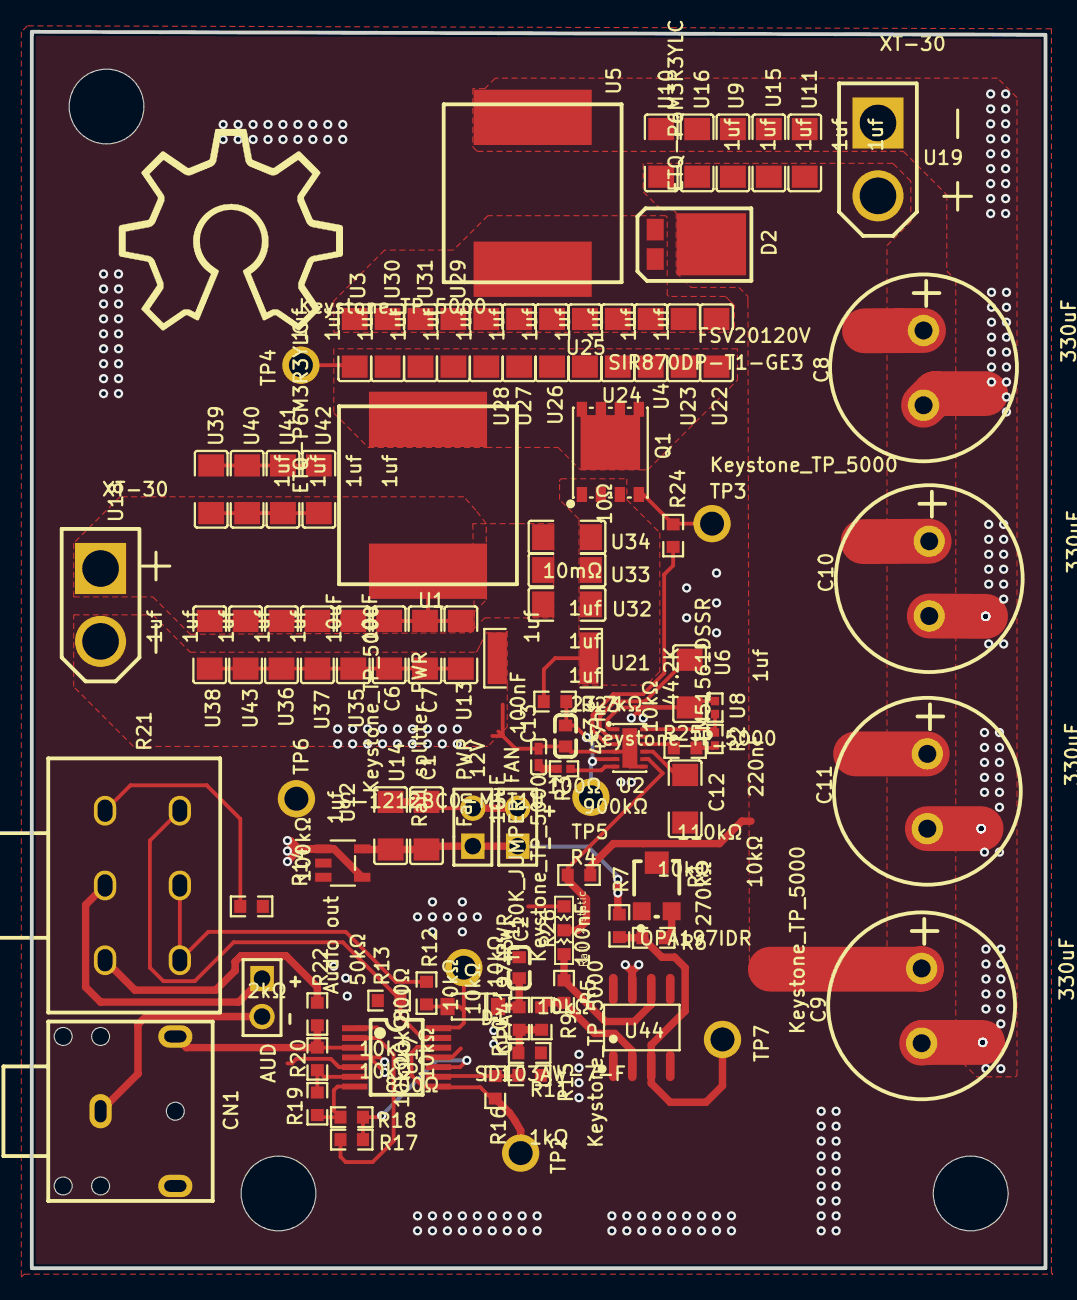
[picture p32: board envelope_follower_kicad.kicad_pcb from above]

Board: 4 copper layers, 67.8 x 82.7 mm, 95 parts (0 on the bottom side), 36 nets.

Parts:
12V: Rail splitter PWR; HDR-M-2.54_1X2
AUD: Audio out; HDR-M-2.54_1X2
C1, C6, C7: 10uF; C1206
C2, C3: 100nF; C0603
C8, C9, C10, C11: 330uF; CAP-TH_BD12.5-P5.00-D0.6-FD
C12: 220nF; C1206
C13: 4.7nF; C0402
CN1: SJ1-3523N; AUDIO-TH_SJ1-3523N
D1: SD103AW-7-F; SOD-123_L2.8-W1.8-LS3.7-RD
D2: FSV20120V
FAN: Fan PWR; HDR-M-2.54_1X2
Hole_gge10732: Hole_gge10732
Hole_gge10771: Hole_gge10771
Hole_gge10801: Hole_gge10801
Q1: SIR870DP-T1-GE3; POWERPAK-SO-8_L5.9-W4.9-P1.27-BL-EP
R1: 10kΩ; RES-ADJ-SMD_3P-L3.0-W3.8-P1.75-BR
R2: 10kΩ; R0402
R3: 23.7kΩ; R0402
R4: 900kΩ; R0603
R5, R6, R9, R10, R15, R16, R17, R18, R19, R20: 10kΩ; R0603
R7: 270kΩ; R0603
R11: 1kΩ; R0603
R12: 50kΩ; R0603
R13, R22: 800Ω; R0603
R14: 100kΩ; RES-ADJ-TH_PDB182-K220K-104B
R21: 2kΩ; R0603
R23: 100Ω; R0603
R24: 10Ω; R0603
R25: 110kΩ; R0603
R26: 10K_JUMPER; RESISTOR_JUMPER_3
TP1, TP2, TP3, TP4, TP5, TP6, TP7: Keystone_TP_5000; KEYSTONE_TP_5000
U1, U5: ETQ-P6M3R3YLC; INDUCTOR FOOTPRINT 10.9*10
U2: LM51561DSSR; WSON-12_L3.0-W2.0-P0.5-BL-EP2.7
U3, U4, U6, U9, U10, U11, U13, U14, U15, U16, U22, U23, U24, U25, U26, U27, U28, U29, U30, U31, U32, U33, U34, U35, U36, U37, U38, U39, U40, U41, U42, U43: 1uf; C1206
U8: 44.2K; R0402
U12: S-1212BC0-M5T1U; SOT-23-5_L2.9-W1.6-P0.95-LS2.8-TL
U17: OPA4197IPWR; TSSOP-14_L5.0-W4.4-P0.65-LS6.4-BL
U18, U19: XT-30
U21: 10mΩ; R2512
U44: OPA197IDR; SOIC-8_L4.9-W3.9-P1.27-LS6.0-BL

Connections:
CN1_3: CN1.3, R20.1, R22.2, U17.3
D2_2: C8.1, C9.1, C10.1, C11.1, D2.2, R4.2, U9.2, U10.2, U11.2, U15.2, U16.2, U19.2
GND: 12V.2, AUD.2, C1.1, C2.1, C3.1, C6.1, C7.1, C8.2, C9.2, C10.2, C11.2, C12.2, C13.1, CN1.1, FAN.2, R1.2, R2.1, R11.1, R13.2, R15.2, R21.1, R25.1, R26.3, TP6.1, U2.4, U2.7, U2.13, U5.1, U9.1, U10.1, U11.1, U12.2, U13.2, U14.2, U15.1, U16.1, U17.5, U17.11, U18.2, U19.1, U21.1, U35.1, U36.1, U37.1, U38.1, U39.1, U40.1, U41.1, U42.1, U43.1, U44.4
Q1_3: Q1.1, Q1.2, Q1.3, R23.2, U21.2, U32.1, U33.1, U34.1
Q1_4: Q1.4, R24.2, TP3.1
Q1_8: Q1.5, Q1.6, Q1.7, Q1.8, TP4.1, U1.2, U3.1, U4.1, U22.1, U23.1, U24.1, U25.1, U26.1, U27.1, U28.1, U29.1, U30.1, U31.1
R1_3: R1.3, R6.2
R3_1: C13.2, R3.1
R6_1: R6.1, R7.2, TP7.1, U44.3
R9_1: R9.1, R10.1, R11.2
R10_2: C2.2, D1.1, R10.2
R12_2: R12.2, R14.5, R14.6
R14_1: R14.1, R21.2
R14_2: AUD.1, R14.2
R14_3: R14.3, R22.1
U2_2: U2.2, U6.1
U2_3: R24.1, U2.3
U2_5: C3.2, R23.1, TP5.1, U2.5
U2_6: R3.2, U2.6
U2_8: R4.1, R26.2, U2.8
U2_9: C12.1, U2.9
U2_10: R25.2, U2.10
U2_12: R2.2, U2.12, U8.1
U3_2: D2.1, U3.2, U4.2, U5.2, U22.2, U23.2, U24.2, U25.2, U26.2, U27.2, U28.2, U29.2, U30.2, U31.2
U12_5: 12V.1, C1.2, FAN.1, R7.1, U12.5, U14.1
U17_1: R17.1, U17.1, U17.2
U17_6: R19.1, R20.2, U17.6
U17_7: R18.1, R19.2, U17.7
U17_8: R16.1, TP2.1, U17.8, U17.12
U17_9: R15.1, R16.2, U17.9
U17_10: R17.2, R18.2, U17.10
U17_13: R13.1, R14.4, U17.13
U17_14: D1.2, R12.1, TP1.1, U17.14
U44_2: R5.1, R9.2, U44.2
U44_6: R5.2, R26.1, U44.6
VCC: C6.2, C7.2, U1.1, U2.1, U6.2, U8.2, U12.1, U12.4, U13.1, U17.4, U18.1, U32.2, U33.2, U34.2, U35.2, U36.2, U37.2, U38.2, U39.2, U40.2, U41.2, U42.2, U43.2, U44.7

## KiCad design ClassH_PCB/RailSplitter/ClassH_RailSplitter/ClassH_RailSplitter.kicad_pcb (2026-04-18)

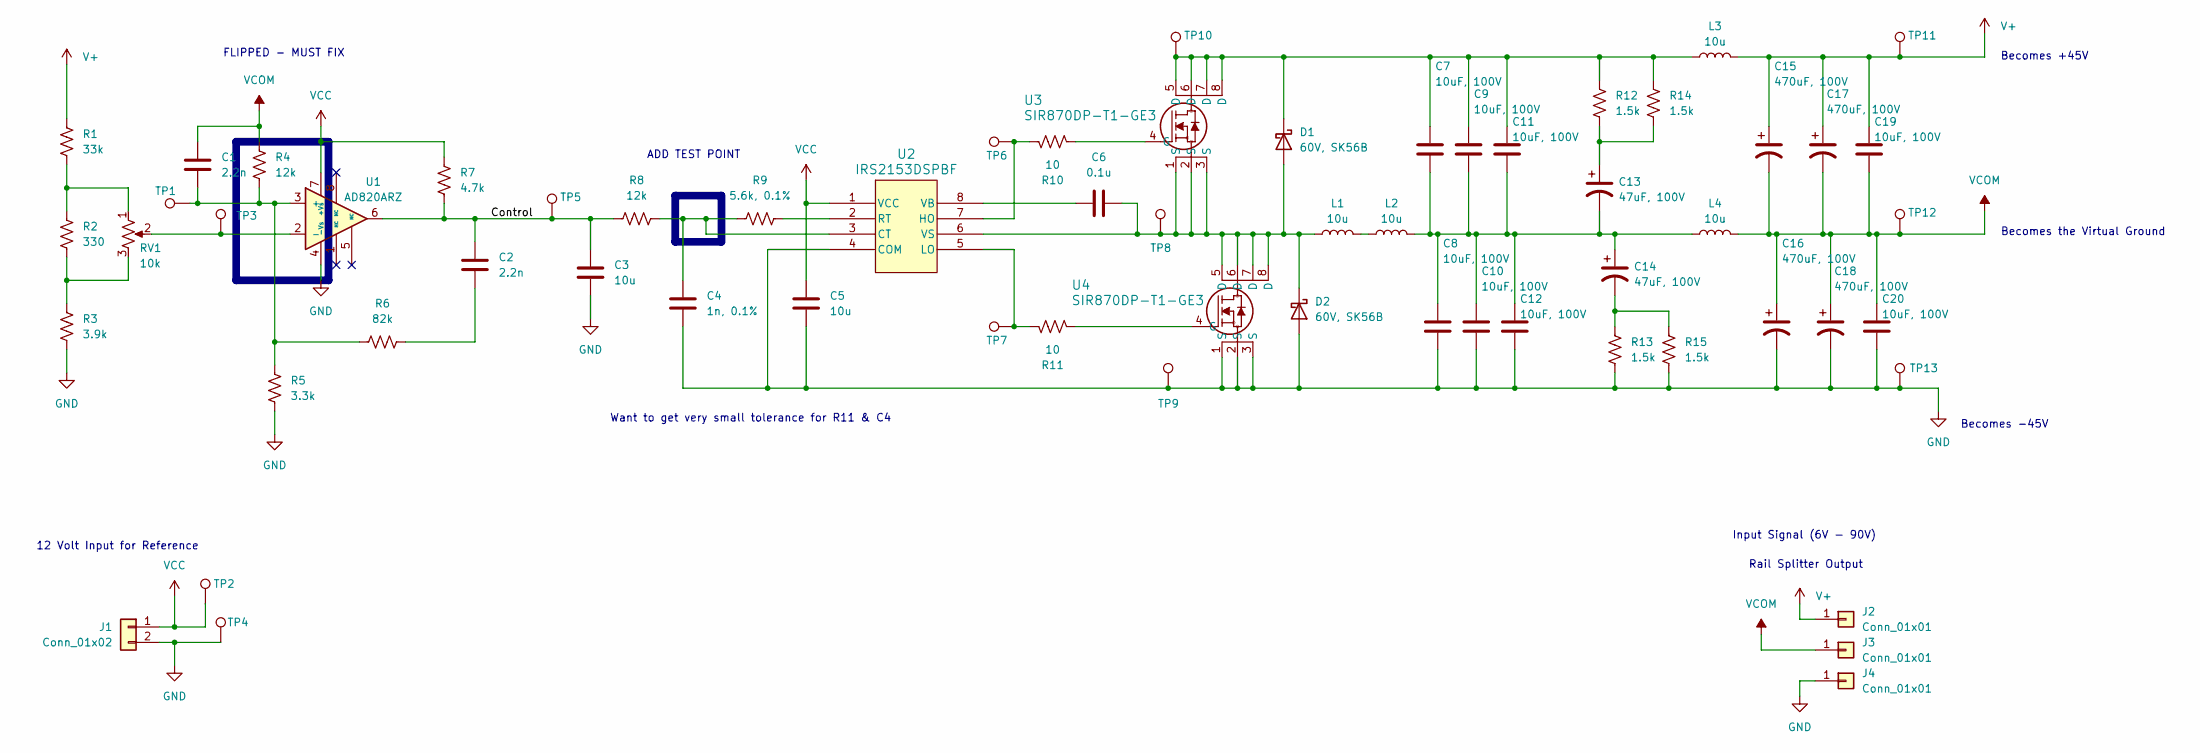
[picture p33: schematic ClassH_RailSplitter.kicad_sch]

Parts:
C1, C2: 2.2n; C_0603_1608Metric_Pad1.08x0.95mm_HandSolder
C3, C5: 10u; C_0805_2012Metric_Pad1.18x1.45mm_HandSolder
C4: 1n, 0.1%; C_0603_1608Metric_Pad1.08x0.95mm_HandSolder
C6: 0.1u; C_0603_1608Metric_Pad1.08x0.95mm_HandSolder
C7, C8, C9, C10, C11, C12, C19, C20: 10uF, 100V; C_1210_3225Metric_Pad1.33x2.70mm_HandSolder
C13, C14: 47uF, 100V; CP_Radial_D10.0mm_P5.00mm
C15, C16, C17, C18: 470uF, 100V; CP_Radial_D16.0mm_P7.50mm
D1, D2: 60V, SK56B; D_SMB_Handsoldering
J1: Conn_01x02; TerminalBlock_MaiXu_MX126-5.0-02P_1x02_P5.00mm
J2, J3, J4: Conn_01x01; MountingHole_5mm_Pad_TopBottom
L1, L2, L3, L4: 10u; IND_ETQP5M100YFC
R1: 33k; R_0603_1608Metric_Pad0.98x0.95mm_HandSolder
R2: 330; R_0603_1608Metric_Pad0.98x0.95mm_HandSolder
R3: 3.9k; R_0603_1608Metric_Pad0.98x0.95mm_HandSolder
R4, R8: 12k; R_0603_1608Metric_Pad0.98x0.95mm_HandSolder
R5: 3.3k; R_0603_1608Metric_Pad0.98x0.95mm_HandSolder
R6: 82k; R_0603_1608Metric_Pad0.98x0.95mm_HandSolder
R7: 4.7k; R_0603_1608Metric_Pad0.98x0.95mm_HandSolder
R9: 5.6k, 0.1%; R_0603_1608Metric_Pad0.98x0.95mm_HandSolder
R10, R11: 10; R_0603_1608Metric_Pad0.98x0.95mm_HandSolder
R12, R13, R14, R15: 1.5k; R_0603_1608Metric_Pad0.98x0.95mm_HandSolder
RV1: 10k; Potentiometer_Bourns_TC33X_Vertical
TP1, TP2, TP3, TP4, TP5, TP6, TP7, TP8, TP9, TP10, TP11, TP12, TP13: TestPoint; TestPoint_Keystone_5005-5009_Compact
U1: AD820ARZ; SOIC127P600X175-8N; MPN AD820ARZ-REEL-REEL7
U2: IRS2153DSPBF; SOIC8_INF
U3, U4: SIR870DP-T1-GE3; MOSFET_7DP-T1-GE3_VIS

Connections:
/Control: C2.1, C3.1, R7.2, R8.1, TP5.1, U1.6
GND: C3.2, C4.2, C5.2, C8.1, C10.1, C12.1, C16.2, C18.2, C20.1, D2.2 (A), J1.2, J4.1, R3.1, R5.1, R13.1, R15.1, TP4.1, TP9.1, TP13.1, U1.4 (-Vs), U2.4 (COM), U4.1 (S), U4.2 (S), U4.3 (S)
unnamed: C2.2, R6.2
unnamed: C7.1, C8.2, C9.1, C10.2, C11.1, C12.2, C13.2, C14.1, L2.2, L4.1
unnamed: C13.1, R12.1, R14.1
unnamed: C14.2, R13.2, R15.2
unnamed: C6.2, D1.2 (A), D2.1 (K), L1.1, TP8.1, U2.6 (VS), U3.1 (S), U3.2 (S), U3.3 (S), U4.5 (D), U4.6 (D), U4.7 (D), U4.8 (D)
unnamed: C7.2, C9.2, C11.2, D1.1 (K), L3.1, R12.2, R14.2, TP10.1, U3.5 (D), U3.6 (D), U3.7 (D), U3.8 (D)
unnamed: L1.2, L2.1
unnamed: R1.2, R2.2, RV1.1
unnamed: R2.1, R3.2, RV1.3
unnamed: C1.2, R4.1, R5.2, R6.1, TP1.1, U1.3 (+)
unnamed: RV1.2, TP3.1, U1.2 (-)
unnamed: C4.1, R8.2, R9.1, U2.3 (CT)
unnamed: R10.1, TP6.1, U2.7 (HO)
unnamed: R11.1, TP7.1, U2.5 (LO)
unnamed: R9.2, U2.2 (RT)
unnamed: C6.1, U2.8 (VB)
unnamed: R10.2, U3.4 (G)
unnamed: R11.2, U4.4 (G)
V+: C15.1, C17.1, C19.2, J2.1, L3.2, R1.1, TP11.1
VCC: C5.1, J1.1, R7.1, TP2.1, U1.7 (+Vs), U2.1 (VCC)
VCOM: C1.1, C15.2, C16.1, C17.2, C18.1, C19.1, C20.2, J3.1, L4.2, R4.2, TP12.1

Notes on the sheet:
Becomes +45V
ADD TEST POINT
Becomes the Virtual Ground
Want to get very small tolerance for R11 & C4
Rail Splitter Output
Input Signal (6V - 90V)
12 Volt Input for Reference
Becomes -45V
FLIPPED - MUST FIX

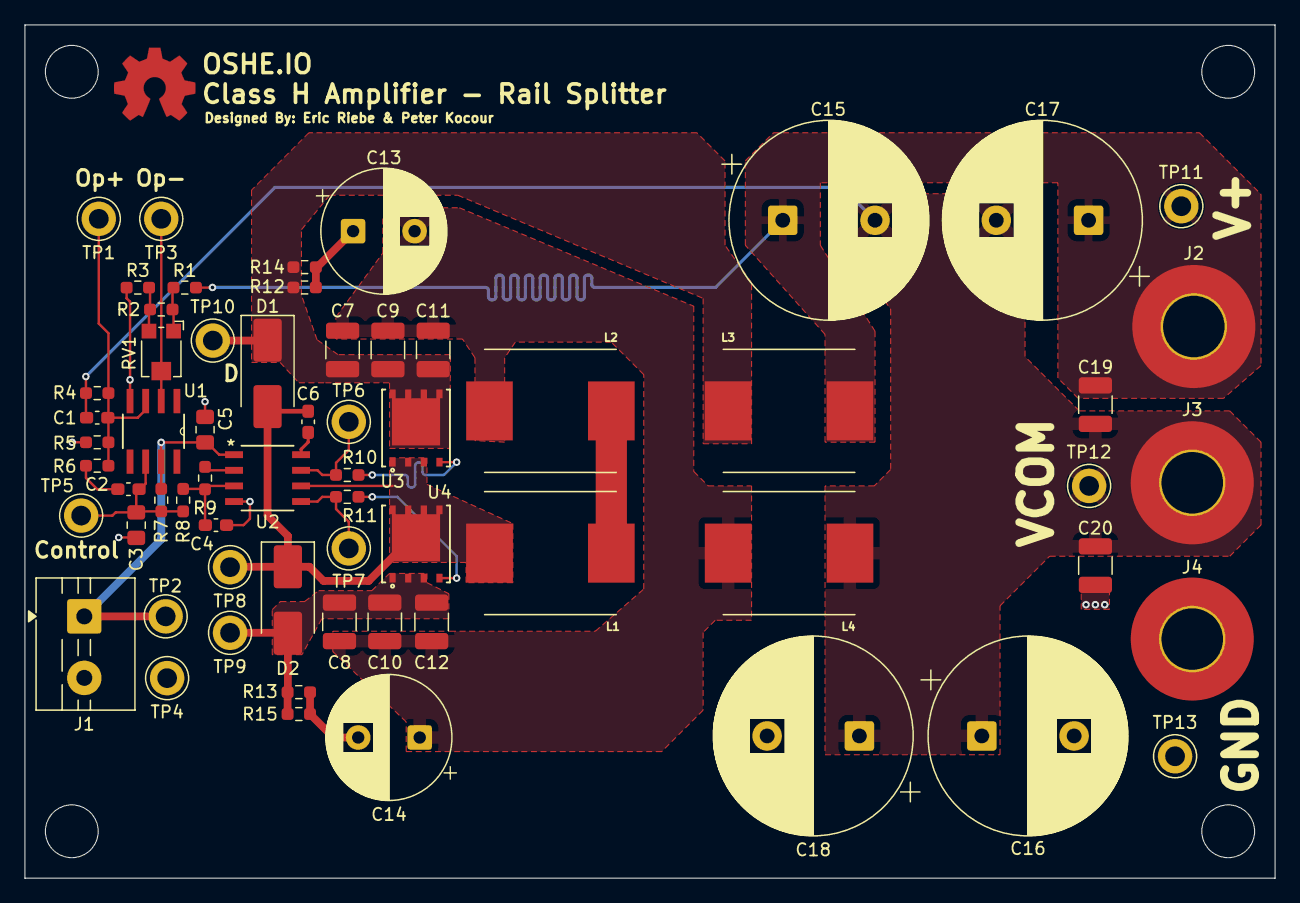
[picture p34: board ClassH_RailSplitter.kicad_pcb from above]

Board: 2 copper layers, 101.6 x 69.3 mm, 63 parts (0 on the bottom side), 23 nets.

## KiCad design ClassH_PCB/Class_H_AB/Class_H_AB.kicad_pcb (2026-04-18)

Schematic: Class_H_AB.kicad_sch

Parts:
C1: 1n; C_1206_3216Metric_Pad1.33x1.80mm_HandSolder
C2: 30p; C_1206_3216Metric_Pad1.33x1.80mm_HandSolder
C3, C4: 0.1u; C_1206_3216Metric_Pad1.33x1.80mm_HandSolder
J1, J2, J3: TB002-500-02BE; CONN_TB002-500-02BE_CUD
Q1, Q3: Q_PNP_ECB; TO-126-3_Vertical
Q2, Q4, Q5: Q_NPN_ECB; TO-126-3_Vertical
Q6: MJL21194; TO545P2030X530X2900-3
Q7: MJL21193G; TO545P2030X530X2900-3; PARTREV 7
R1, R2: 1k; R_0805_2012Metric_Pad1.20x1.40mm_HandSolder
R3: 20k; R_1206_3216Metric_Pad1.30x1.75mm_HandSolder
R4, R9, R10: 100; R_0805_2012Metric_Pad1.20x1.40mm_HandSolder
R5, R6: 40k; R_0805_2012Metric_Pad1.20x1.40mm_HandSolder
R7: 3.6k; R_1206_3216Metric_Pad1.30x1.75mm_HandSolder
R8: 1.1k; R_0805_2012Metric_Pad1.20x1.40mm_HandSolder
R11: 330; R_1206_3216Metric_Pad1.30x1.75mm_HandSolder
R12, R13: 0.33; R_1020_2550Metric_Pad1.33x5.20mm_HandSolder
R14: PV36W102C01B00; POT_PV36W_MUR
TP1, TP2, TP3, TP4, TP5, TP6, TP7, TP8, TP9, TP10, TP11, TP12: 5000; KEYSTONE_5000; PARTREV H
U1: OPA454AIDDA; DDA0008J_NV
U2, U4: MJE15032G; TO-220AB_ONS
U3, U5: MJE15033G; TO-220AB_ONS

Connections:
/OUT: R4.1, TP1.TP, U1.6 (OUT)
/Rf: J1.1, R3.2, R12.2, R13.1, TP12.TP
/VDD: C3.1, J2.1, Q1.1 (E), Q6.2, R9.1, U1.7 (V+), U2.2 (C), U4.2 (C)
/VSS: C2.2, C4.1, J2.2, Q2.1 (E), Q7.2, R10.2, U1.1 (E_D_Com), U1.4 (V-), U3.3 (E), U5.3 (E)
GND: C1.2, C3.2, C4.2, J1.2, J3.1, R1.1, R5.2, R6.1
unnamed: J3.2, R2.2
unnamed: Q1.3 (B), Q3.1 (E), R9.2, TP10.TP
unnamed: Q1.2 (C), Q3.3 (B), R5.1
unnamed: Q2.3 (B), Q4.1 (E), R10.1, TP11.TP
unnamed: Q2.2 (C), Q4.3 (B), R6.2
unnamed: Q3.2 (C), Q5.2 (C), R7.1, TP2.TP, TP8.TP, U2.1 (B)
unnamed: Q4.2 (C), Q5.1 (E), R4.2, R8.2, TP3.TP, TP9.TP, U3.1 (B)
unnamed: Q5.3 (B), R14.2
unnamed: Q6.3, R12.1, TP6.TP
unnamed: Q7.3, R13.2, TP7.TP
unnamed: R7.2, R14.1
unnamed: R8.1, R14.3
unnamed: C2.1, U1.8 (E_D)
unnamed: C1.1, R2.1, U1.3 (IN+)
unnamed: R1.2, R3.1, U1.2 (IN-)
unnamed: U2.3 (E), U4.1 (B)
unnamed: U3.2 (C), U5.1 (B)
unnamed: Q6.1, R11.1, TP4.TP, U4.3 (E)
unnamed: Q7.1, R11.2, TP5.TP, U5.2 (C)

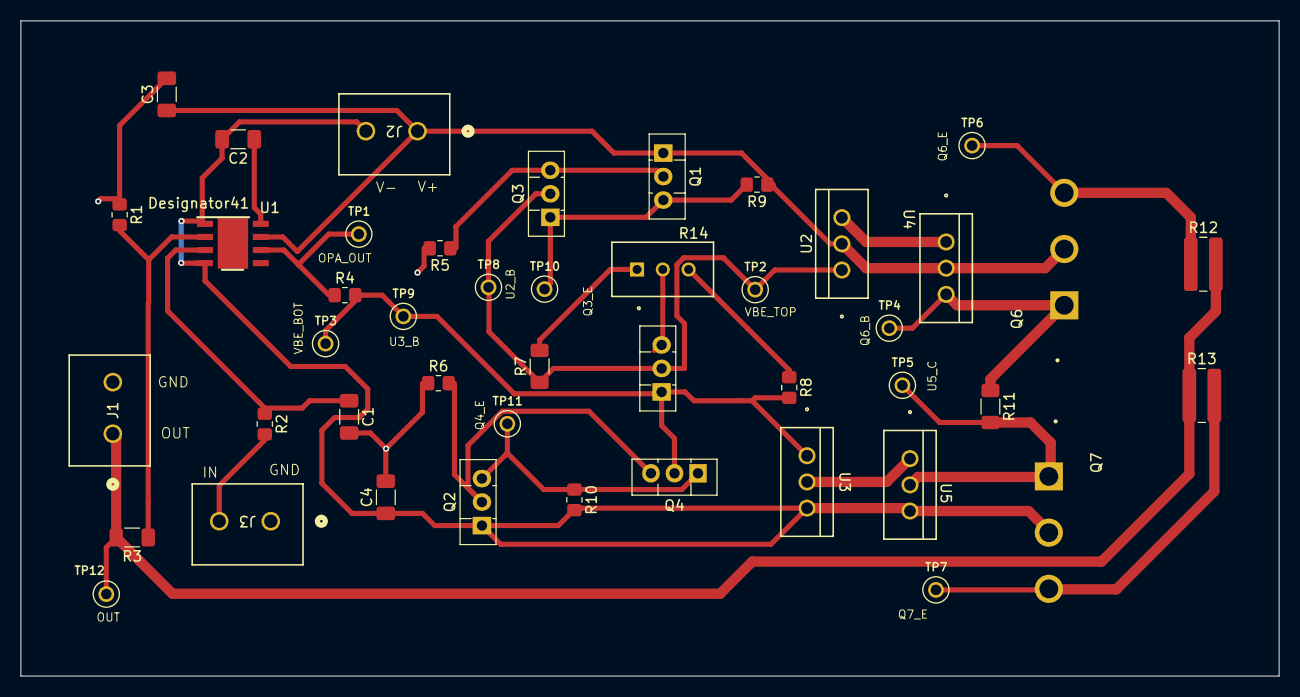
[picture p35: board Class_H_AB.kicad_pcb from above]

Board: 2 copper layers, 122.0 x 63.5 mm, 45 parts (0 on the bottom side), 24 nets.

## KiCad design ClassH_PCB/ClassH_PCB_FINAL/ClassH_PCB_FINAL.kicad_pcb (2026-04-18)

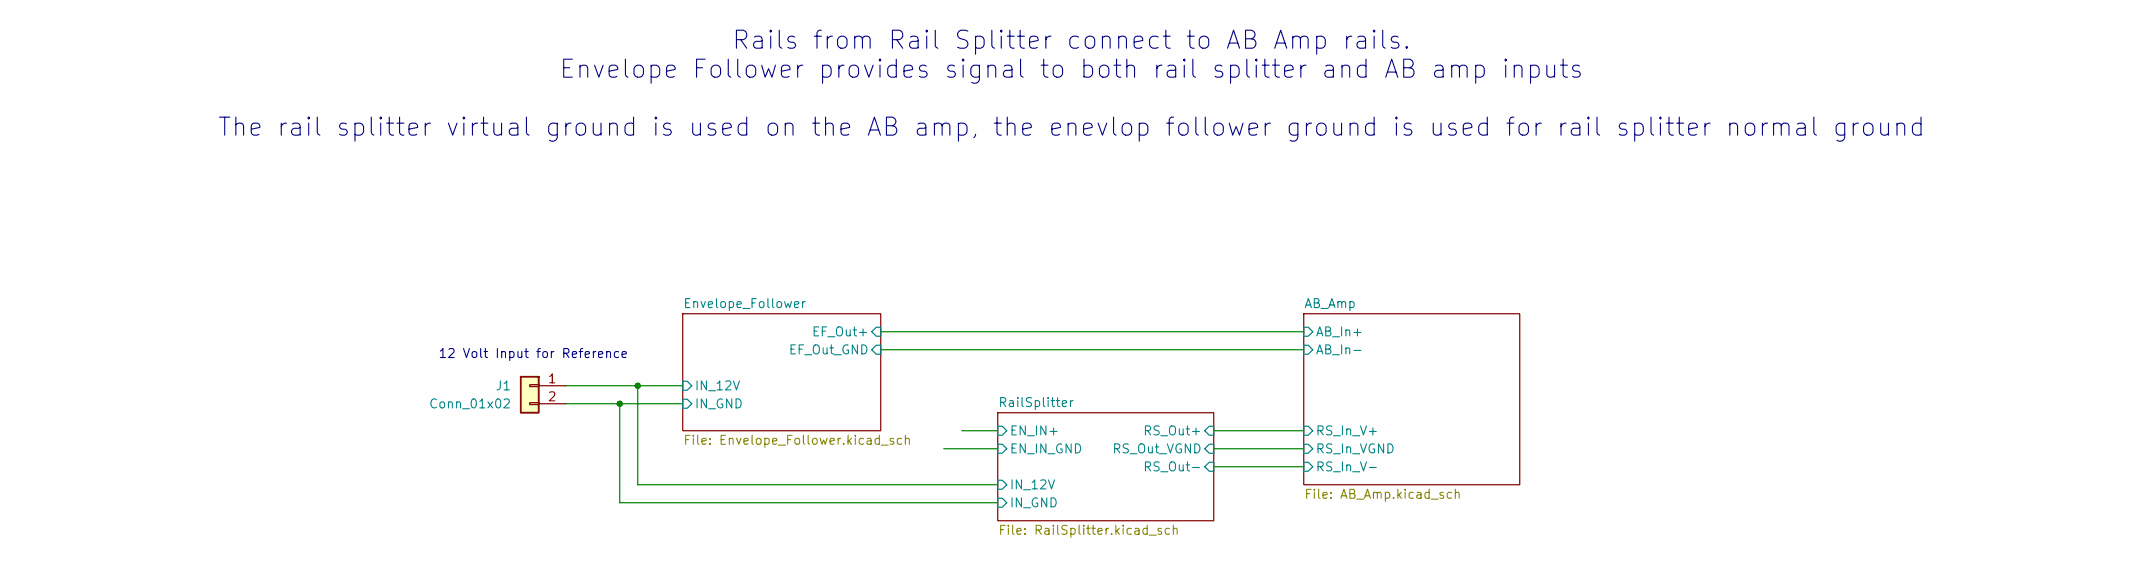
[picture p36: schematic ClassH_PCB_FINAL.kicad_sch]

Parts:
J1: Conn_01x02; TerminalBlock_MaiXu_MX126-5.0-02P_1x02_P5.00mm

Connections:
GND: J1.2; also elsewhere on the board
VCC: J1.1; also elsewhere on the board

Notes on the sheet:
Rails from Rail Splitter connect to AB Amp rails. Envelope Follower provides signal to both rail splitter and AB amp inputs The rail splitter virtual ground is used on the AB amp, the enevlop follower ground is used for rail splitter normal ground
12 Volt Input for Reference

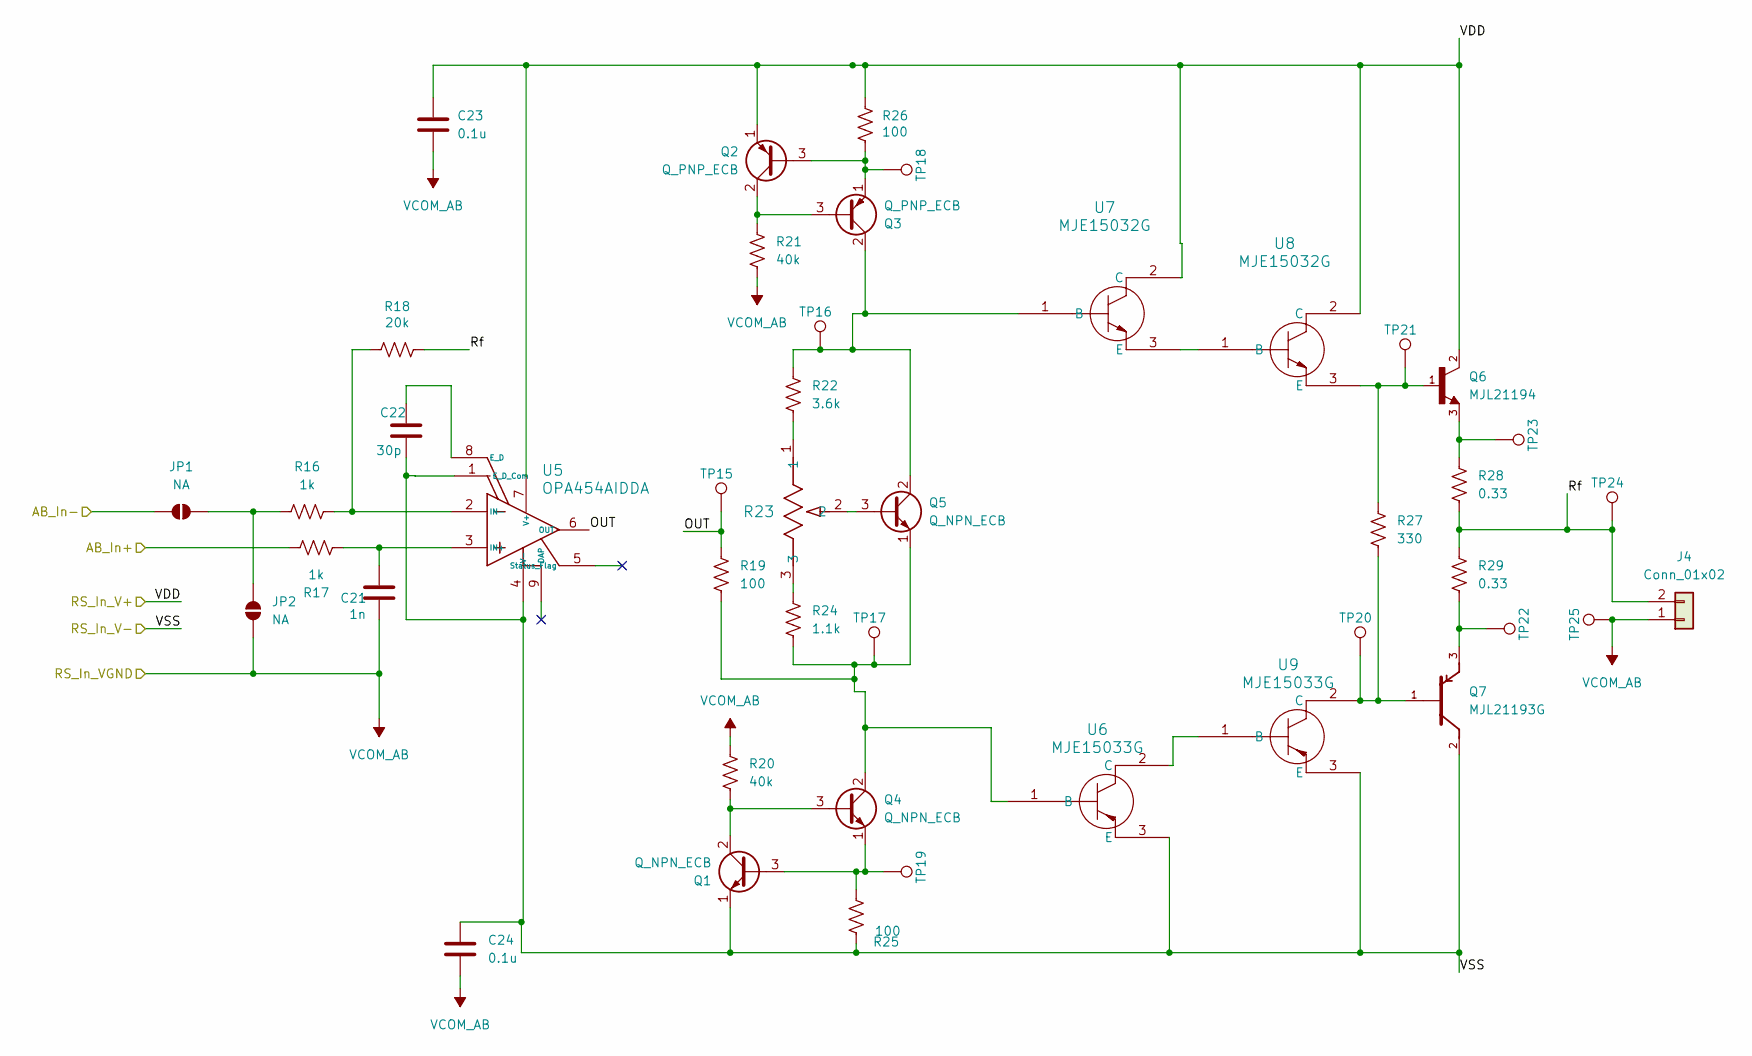
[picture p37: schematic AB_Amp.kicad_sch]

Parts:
C21: 1n; C_1206_3216Metric_Pad1.33x1.80mm_HandSolder
C22: 30p; C_1206_3216Metric_Pad1.33x1.80mm_HandSolder
C23, C24: 0.1u; C_1206_3216Metric_Pad1.33x1.80mm_HandSolder
J4: Conn_01x02; TerminalBlock_MaiXu_MX126-5.0-02P_1x02_P5.00mm
JP1, JP2: NA; SolderJumper-2_P1.3mm_Open_Pad1.0x1.5mm
Q1, Q4, Q5: Q_NPN_ECB; TO-126-3_Vertical
Q2, Q3: Q_PNP_ECB; TO-126-3_Vertical
Q6: MJL21194; TO545P2030X530X2900-3
Q7: MJL21193G; TO545P2030X530X2900-3; PARTREV 7
R16, R17: 1k; R_0805_2012Metric_Pad1.20x1.40mm_HandSolder
R18: 20k; R_1206_3216Metric_Pad1.30x1.75mm_HandSolder
R19, R25, R26: 100; R_0805_2012Metric_Pad1.20x1.40mm_HandSolder
R20, R21: 40k; R_0805_2012Metric_Pad1.20x1.40mm_HandSolder
R22: 3.6k; R_1206_3216Metric_Pad1.30x1.75mm_HandSolder
R23: PV36W102C01B00; POT_PV36W_MUR
R24: 1.1k; R_0805_2012Metric_Pad1.20x1.40mm_HandSolder
R27: 330; R_1206_3216Metric_Pad1.30x1.75mm_HandSolder
R28, R29: 0.33; R_1020_2550Metric_Pad1.33x5.20mm_HandSolder
TP15, TP16, TP17, TP18, TP19, TP20, TP21, TP22, TP23, TP24, TP25: TestPoint; TestPoint_Keystone_5005-5009_Compact
U5: OPA454AIDDA; DDA0008J_NV
U6, U9: MJE15033G; TO-220AB_ONS
U7, U8: MJE15032G; TO-220AB_ONS

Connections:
/AB_Amp/AB_In+: R17.2; also elsewhere on the board
/AB_Amp/AB_In-: JP1.2 (B); also elsewhere on the board
/AB_Amp/OUT: R19.1, TP15.1, U5.6 (OUT)
/AB_Amp/Rf: J4.2, R18.2, R28.2, R29.1, TP24.1
GND: C22.2, C24.1, Q1.1 (E), Q7.2, R25.2, U5.1 (E_D_Com), U5.4 (V-), U6.3 (E), U9.3 (E); also elsewhere on the board
unnamed: JP1.1 (A), JP2.2 (B), R16.1
unnamed: Q1.3 (B), Q4.1 (E), R25.1, TP19.1
unnamed: Q1.2 (C), Q4.3 (B), R20.2
unnamed: Q2.3 (B), Q3.1 (E), R26.2, TP18.1
unnamed: Q2.2 (C), Q3.3 (B), R21.1
unnamed: Q3.2 (C), Q5.2 (C), R22.1, TP16.1, U7.1 (B)
unnamed: Q4.2 (C), Q5.1 (E), R19.2, R24.2, TP17.1, U6.1 (B)
unnamed: Q5.3 (B), R23.2
unnamed: Q6.3, R28.1, TP23.1
unnamed: Q7.3, R29.2, TP22.1
unnamed: R22.2, R23.1
unnamed: R23.3, R24.1
unnamed: C22.1, U5.8 (E_D)
unnamed: C21.1, R17.1, U5.3 (IN+)
unnamed: R16.2, R18.1, U5.2 (IN-)
unnamed: U6.2 (C), U9.1 (B)
unnamed: U7.3 (E), U8.1 (B)
unnamed: Q6.1, R27.1, TP21.1, U8.3 (E)
unnamed: Q7.1, R27.2, TP20.1, U9.2 (C)
V+: C23.1, Q2.1 (E), Q6.2, R26.1, U5.7 (V+), U7.2 (C), U8.2 (C); also elsewhere on the board
VCOM: C21.2, C23.2, C24.2, J4.1, JP2.1 (A), R20.1, R21.2, TP25.1; also elsewhere on the board

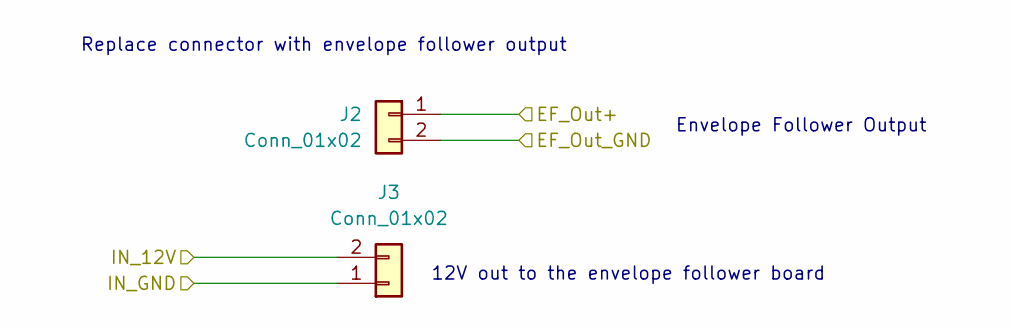
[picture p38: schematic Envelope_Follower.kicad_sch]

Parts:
J2, J3: Conn_01x02; TerminalBlock_MaiXu_MX126-5.0-02P_1x02_P5.00mm

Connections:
/AB_Amp/AB_In+: J2.1; also elsewhere on the board
/AB_Amp/AB_In-: J2.2; also elsewhere on the board
GND: J3.1; also elsewhere on the board
VCC: J3.2; also elsewhere on the board

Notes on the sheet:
Envelope Follower Output
Replace connector with envelope follower output
12V out to the envelope follower board

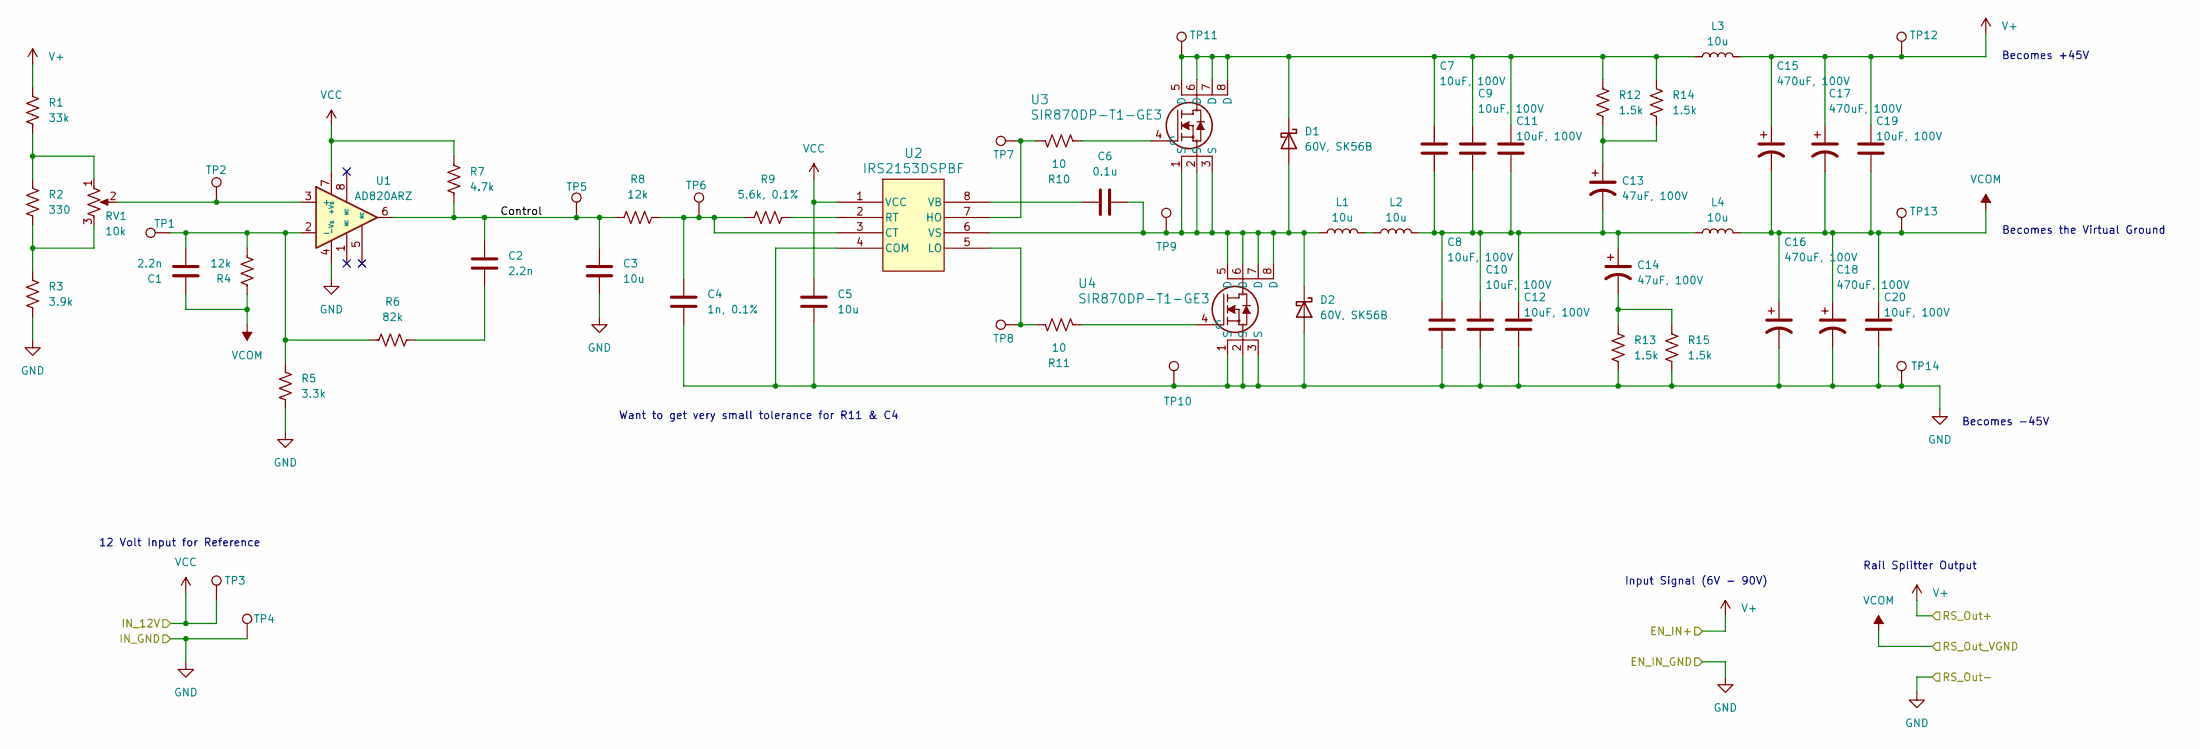
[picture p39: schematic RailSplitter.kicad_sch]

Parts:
C1, C2: 2.2n; C_0603_1608Metric_Pad1.08x0.95mm_HandSolder
C3, C5: 10u; C_0805_2012Metric_Pad1.18x1.45mm_HandSolder
C4: 1n, 0.1%; C_0603_1608Metric_Pad1.08x0.95mm_HandSolder
C6: 0.1u; C_0603_1608Metric_Pad1.08x0.95mm_HandSolder
C7, C8, C9, C10, C11, C12, C19, C20: 10uF, 100V; C_1210_3225Metric_Pad1.33x2.70mm_HandSolder
C13, C14: 47uF, 100V; CP_Radial_D10.0mm_P5.00mm
C15, C16, C17, C18: 470uF, 100V; CP_Radial_D16.0mm_P7.50mm
D1, D2: 60V, SK56B; D_SMB_Handsoldering
L1, L2, L3, L4: 10u; IND_ETQP5M100YFC
R1: 33k; R_0603_1608Metric_Pad0.98x0.95mm_HandSolder
R2: 330; R_0603_1608Metric_Pad0.98x0.95mm_HandSolder
R3: 3.9k; R_0603_1608Metric_Pad0.98x0.95mm_HandSolder
R4, R8: 12k; R_0603_1608Metric_Pad0.98x0.95mm_HandSolder
R5: 3.3k; R_0603_1608Metric_Pad0.98x0.95mm_HandSolder
R6: 82k; R_0603_1608Metric_Pad0.98x0.95mm_HandSolder
R7: 4.7k; R_0603_1608Metric_Pad0.98x0.95mm_HandSolder
R9: 5.6k, 0.1%; R_0603_1608Metric_Pad0.98x0.95mm_HandSolder
R10, R11: 10; R_0603_1608Metric_Pad0.98x0.95mm_HandSolder
R12, R13, R14, R15: 1.5k; R_0603_1608Metric_Pad0.98x0.95mm_HandSolder
RV1: 10k; Potentiometer_Bourns_TC33X_Vertical
TP1, TP2, TP3, TP4, TP5, TP6, TP7, TP8, TP9, TP10, TP11, TP12, TP13, TP14: TestPoint; TestPoint_Keystone_5005-5009_Compact
U1: AD820ARZ; SOIC127P600X175-8N; MPN AD820ARZ-REEL-REEL7
U2: IRS2153DSPBF; SOIC8_INF
U3, U4: SIR870DP-T1-GE3; MOSFET_7DP-T1-GE3_VIS

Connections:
/RailSplitter/Control: C2.1, C3.1, R7.2, R8.1, TP5.1, U1.6
GND: C3.2, C4.2, C5.2, C8.1, C10.1, C12.1, C16.2, C18.2, C20.1, D2.2 (A), R3.1, R5.1, R13.1, R15.1, TP4.1, TP10.1, TP14.1, U1.4 (-Vs), U2.4 (COM), U4.1 (S), U4.2 (S), U4.3 (S); also elsewhere on the board
unnamed: C2.2, R6.2
unnamed: C7.1, C8.2, C9.1, C10.2, C11.1, C12.2, C13.2, C14.1, L2.2, L4.1
unnamed: C13.1, R12.1, R14.1
unnamed: C14.2, R13.2, R15.2
unnamed: C6.2, D1.2 (A), D2.1 (K), L1.1, TP9.1, U2.6 (VS), U3.1 (S), U3.2 (S), U3.3 (S), U4.5 (D), U4.6 (D), U4.7 (D), U4.8 (D)
unnamed: C7.2, C9.2, C11.2, D1.1 (K), L3.1, R12.2, R14.2, TP11.1, U3.5 (D), U3.6 (D), U3.7 (D), U3.8 (D)
unnamed: L1.2, L2.1
unnamed: R1.2, R2.2, RV1.1
unnamed: R2.1, R3.2, RV1.3
unnamed: RV1.2, TP2.1, U1.3 (+)
unnamed: C1.2, R4.1, R5.2, R6.1, TP1.1, U1.2 (-)
unnamed: C4.1, R8.2, R9.1, TP6.1, U2.3 (CT)
unnamed: R10.1, TP7.1, U2.7 (HO)
unnamed: R11.1, TP8.1, U2.5 (LO)
unnamed: R9.2, U2.2 (RT)
unnamed: C6.1, U2.8 (VB)
unnamed: R10.2, U3.4 (G)
unnamed: R11.2, U4.4 (G)
V+: C15.1, C17.1, C19.2, L3.2, R1.1, TP12.1; also elsewhere on the board
VCC: C5.1, R7.1, TP3.1, U1.7 (+Vs), U2.1 (VCC); also elsewhere on the board
VCOM: C1.1, C15.2, C16.1, C17.2, C18.1, C19.1, C20.2, L4.2, R4.2, TP13.1; also elsewhere on the board

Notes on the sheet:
Want to get very small tolerance for R11 & C4
Becomes +45V
Rail Splitter Output
Becomes -45V
Becomes the Virtual Ground
12 Volt Input for Reference
Input Signal (6V - 90V)

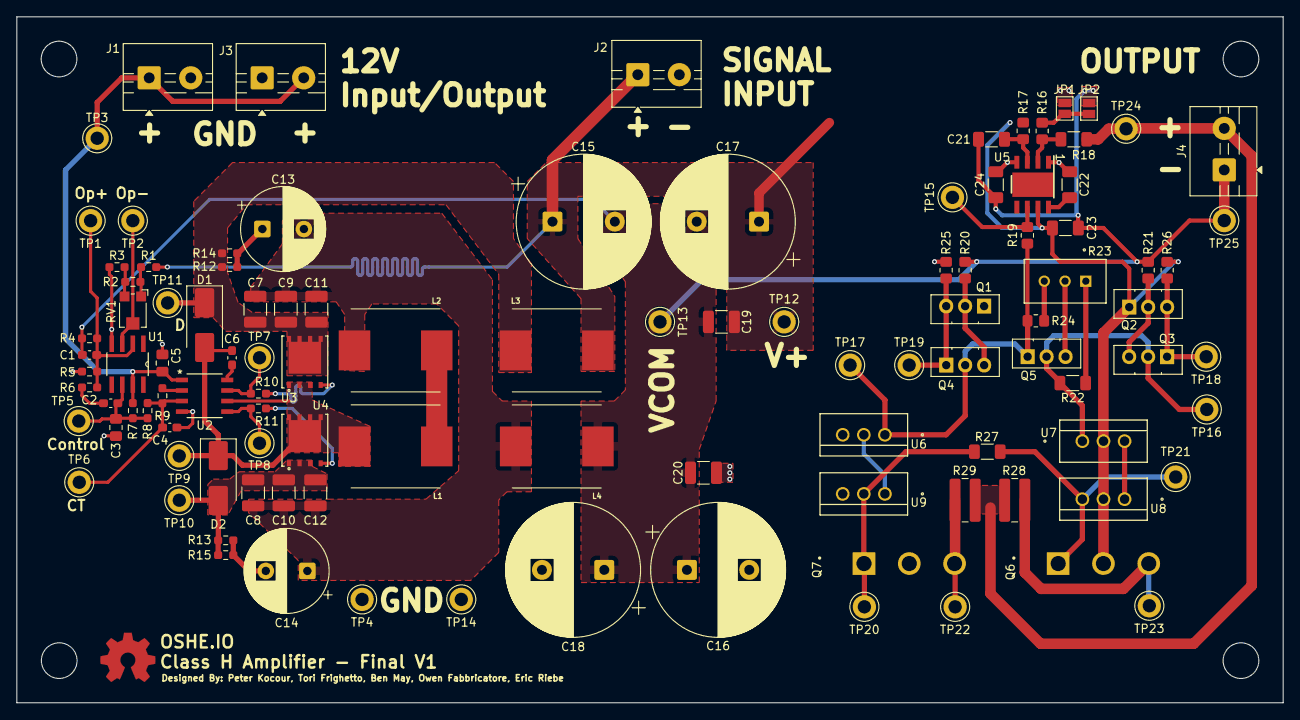
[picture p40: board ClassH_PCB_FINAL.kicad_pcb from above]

Board: 2 copper layers, 152.4 x 82.6 mm, 107 parts (0 on the bottom side), 46 nets.
